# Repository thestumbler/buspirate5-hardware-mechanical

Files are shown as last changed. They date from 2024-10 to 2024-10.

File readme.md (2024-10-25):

# Bus Pirate 5, Mechanical Envelope Drawing

This repo has some scripts to enable semi-automatic preparation of
mechanical envelope drawing of the Bus Pirate 5 enclosure. 

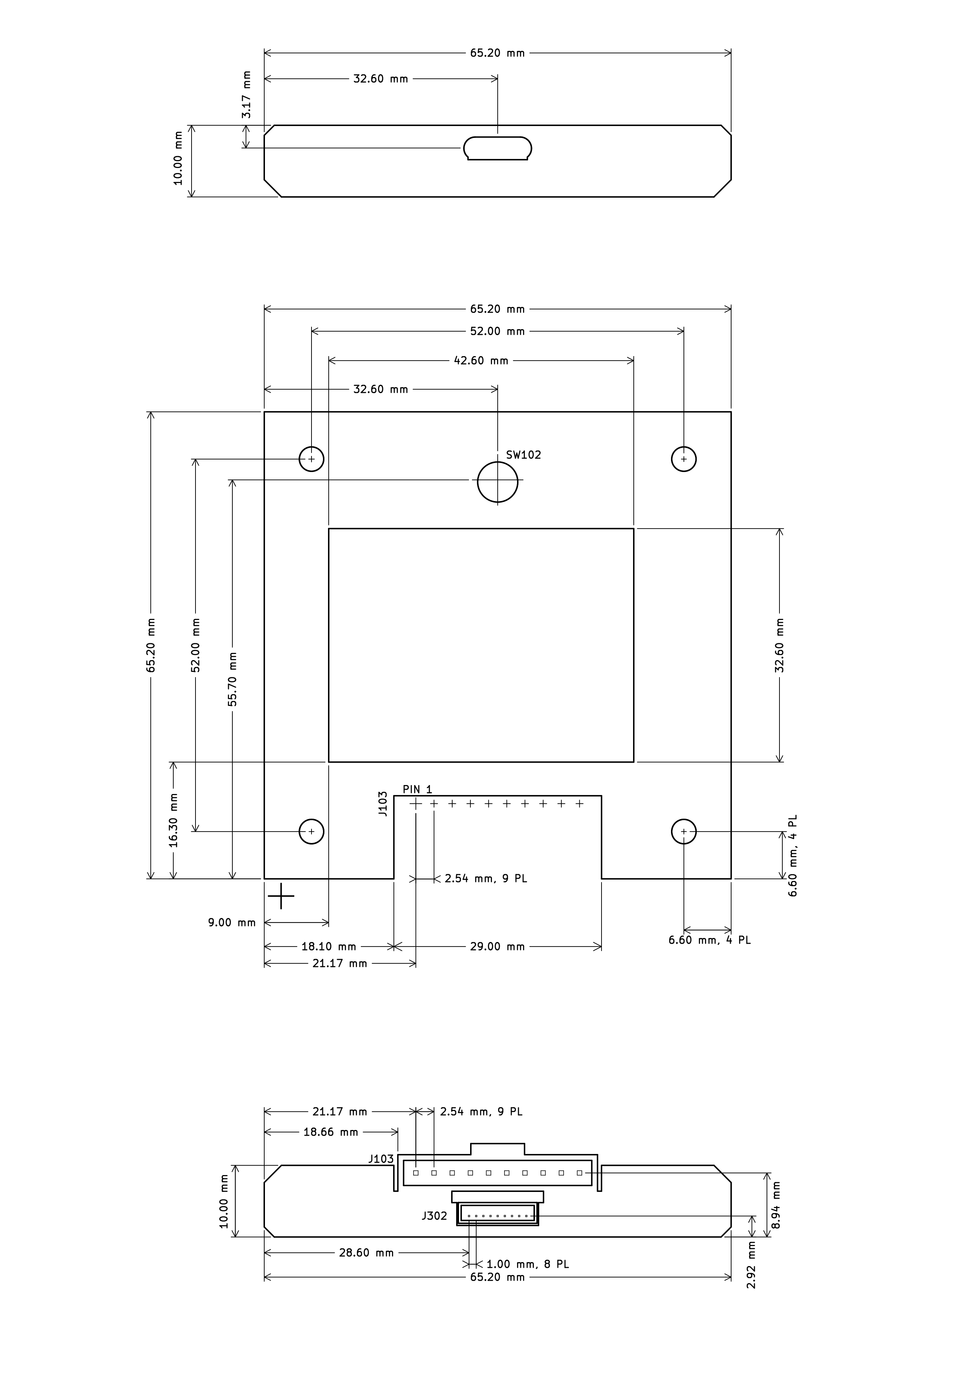
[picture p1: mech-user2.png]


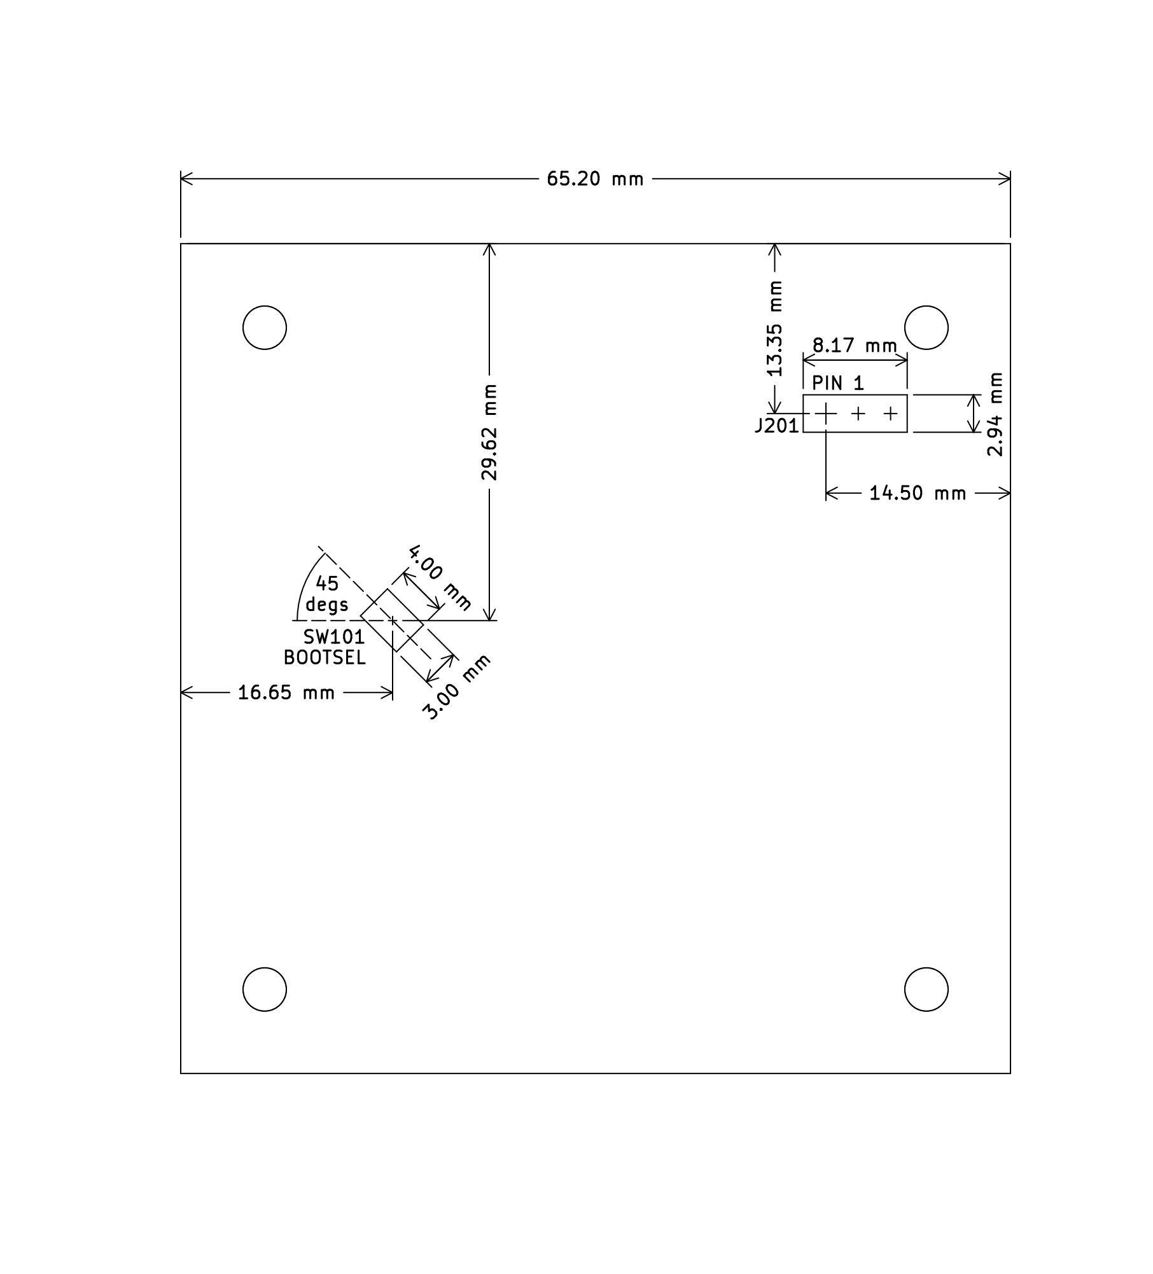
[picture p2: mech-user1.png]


## Background

The enclosure is designed in OpenSCAD. Getting 2D dimension drawings out
of OpenSCAD, while possible, is awkward ( see this [repo](
https://github.com/pwpearson/dimensional-drawings.git) for example ).
It is straightforward to make an XY projection or cut of an object. 
And KiCad has basic dimensioning for several versions now. So the
approach taken is

(1) create projections using OpenSCAD design
(2) save as DXF files, import into KiCad
(3) add dimensioning in KiCad

## OpenSCAD Projections

The file `make2d.scad` contains the for projecting the
different views. The code is organized as follows:

* module fiducial()
* module scad2kicad()
* module scad2kicad_sides()
* module project()
* module project_aux_side()
* module project_usb_side()
* // Main Slicing Code...

In summary, this requires the following 
operations (details are in the code):

* X-Y translation
* Mirroring
* Rotation
* Matching origin

This code could be put directly in the SCAD file. But there are several
versions to deal with, and it would be nice to keep this code separate.
The code is substantially independent, although it reaches into the
enclosure file to get the objects needed.

The only problem encountered with this approach is with OpenSCAD
importing of modules.

* If you `include` a file, you pickup all the modules and variables, but
  you also get any objects that are drawn in the main code.

* If you `use` a file, you get all the modules, any objects are not
  drawn, but you don't get the variables.

I don't have a solution for this. What I did was a compromise. I moved
all the parameters in the enclosure design to a file `params.scad`. 
If this is adopted, then all the versions of the enclosure would need to
carve out the variables into separate parameter files.

One other option is to organize the enclosure files so they don't create
any mainline objects without a control flag. This makes is easy to
include the files as-is, and use flags in the user customizer panel. See
`make2d.scad` for an example of this.

## KiCad Import

Importing the DXF files into KiCad is made easy by positioning the XY
projections in OpenSCAD so they match the exact placement of the PCB in
KiCAD. You can just import the files referenced to (0,0) and there is no
need to use interactive placement.

Four new layers are created as follows:

* User1  Bottom XY projection
* User2  Top and Sides projections
* User3  Bottom dimensions
* User4  Top and Sides dimensions

Dimensions are made by hand. 

## Revisions

All these four layers are kept in a separete PCB design `mech`. This
deisng only has four layers, the four user layers. If you make a new
BusPirate revision, you to the `append board` operation to add these to
the design.

If there are changes to the enclosure design, you have to remake the DXF
files and reimport them into KiCad. For most changes, it is easy to 
tweak the dimension layers to match any changes. The shell script
`make2d.sh` creates all four DXF files at once. 

As currently coded, you meed to manually edit the include statement in
make2d.scad (the target file of an include/use cannot be a variable).

# Resources

- [Download the latest firmware build](https://forum.buspirate.com/t/bus-pirate-5-auto-build-main-branch/20/99999)
- [Get help and chat in the forum](https://forum.buspirate.com/)
- [Firmware documentation](https://firmware.buspirate.com/) ([source](https://github.com/DangerousPrototypes/BusPirate5-docs-firmware))
- [Hardware documentation](https://hardware.buspirate.com/) ([source](https://github.com/DangerousPrototypes/BusPirate5-docs-hardware))
- [Hardware repo](https://github.com/DangerousPrototypes/BusPirate5-hardware)
- [Firmware repo](https://github.com/DangerousPrototypes/BusPirate5-firmware)

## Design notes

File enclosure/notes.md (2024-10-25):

button hole

line widths plotting

side projections nightmare

import board

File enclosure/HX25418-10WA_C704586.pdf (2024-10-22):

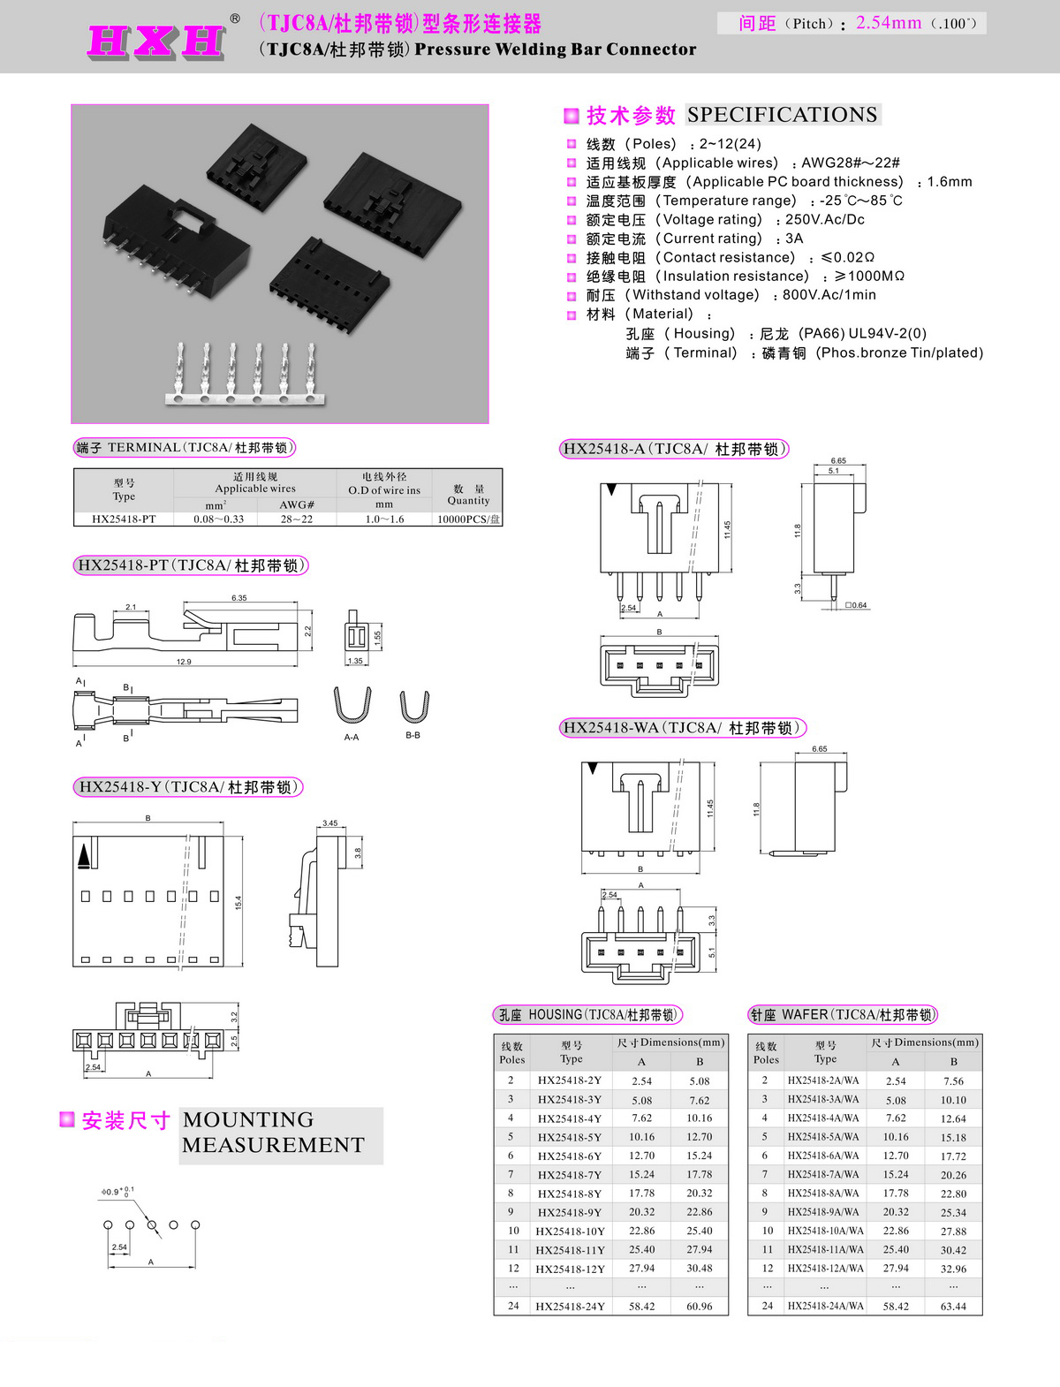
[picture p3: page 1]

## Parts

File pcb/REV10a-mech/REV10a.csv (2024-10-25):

Source: | C:\buspirate5-hardware\pcb\REV10a\REV10a.kicad_sch
Date: | 2/22/2024 12:56:02 PM
Tool: | Eeschema 7.0.7
Generator: | C:\Program Files\KiCad\7.0\bin\scripting\plugins/bom_csv_grouped_by_value.py
Component Count: | 220
Collated Components:
Item | Qty | Reference(s) | Value | LibPart | Footprint | Datasheet | DNP | Field4 | Field5 | Field6 | RMB | Sim.Device | Sim.Pins | Supplier | USD
1 | 58 | C103, C110, C111, C112, C113, C114, C115, C116, C117, C118, C121, C301, C302, C303, C304, C305, C306, C307, C308, C309, C310, C311, C312, C313, C314, C315, C316, C403, C406, C414, C415, C416, C501, C502, C503, C506, C508, C510, C602, C605, C701, C702, C703, C704, C705, C706, C707, C708, C710, C712, C713, C714, C715, C716, C717, C718, C719, C720 | 0.1uF | Device:C_Small | Capacitor_SMD:C_0402_1005Metric | ~ |  |  |  |  | 0.00628 |  |  | https://item.szlcsc.com/1877.html
2 | 10 | C104, C107, C108, C109, C405, C413, C504, C507, C509, C601 | 2.2uF | Device:C_Small | Capacitor_SMD:C_0402_1005Metric | ~ |  |  |  |  | 0.043101 |  |  | https://item.szlcsc.com/108589.html
3 | 2 | C105, C106 | 15pF | Device:C_Small | Capacitor_SMD:C_0402_1005Metric | ~ |  |  |  |  | 0.022142 |  |  | https://item.szlcsc.com/306263.html
4 | 6 | C201, C202, C401, C402, C404, C407 | 4.7uF | Device:C_Small | Capacitor_SMD:C_0402_1005Metric | ~ |  |  |  |  | 0.037726 |  |  | https://item.szlcsc.com/1877.html
5 | 1 | C408 | 120pF | Device:C_Small | Capacitor_SMD:C_0402_1005Metric | ~ |  |  |  |  | 0.037726 |  |  | https://item.szlcsc.com/1877.html
6 | 1 | C603 | DNF | Device:C_Small | Capacitor_SMD:C_0402_1005Metric | ~
7 | 4 | D401, D601, D602, D603 | 1N4148WT | Diode:1N4148WS | Diode_SMD:D_SOD-523 | https://www.vishay.com/docs/85751/1n4148ws.pdf |  |  |  |  | 0.182079 | D | 1=K 2=A | https://item.szlcsc.com/120141.html
8 | 5 | D500, D501, D502, D503, D504 | BAS40T-05 | Diode:BAT54C | Package_TO_SOT_SMD:SOT-523 | http://www.diodes.com/_files/datasheets/ds11005.pdf
9 | 5 | FID1, FID2, FID3, FID4, FID5 | Fiducial | Mechanical:Fiducial | Fiducial:Fiducial_1mm_Mask2mm | ~
10 | 4 | H1, H2, H3, H4 | MountingHole | Mechanical:MountingHole | MountingHole:MountingHole_3.2mm_M3 | ~
11 | 1 | J201 | Conn_01x03 | Connector_Generic:Conn_01x03 | Connector_PinSocket_2.54mm:PinSocket_1x03_P2.54mm_Vertical | ~
12 | 1 | J202 | TYPE-C-31-M-12 | :TYPE-C-31-M-12_2 | usb-c:HRO_TYPE-C-31-M-12 | HRO Electronics |  | 3.31mm | A | Manufacturer Recommendations
13 | 1 | J301 | Conn_01x10 | Connector_Generic:Conn_01x10 | Connector_PinHeader_2.54mm:PinHeader_1x10_P2.54mm_Vertical | ~
14 | 1 | J302 | Conn_01x09 | Connector_Generic:Conn_01x09 | Connector_JST:JST_SH_SM09B-SRSS-TB_1x09-1MP_P1.00mm_Horizontal | ~
15 | 1 | L201 | 1.5A | kicad5-device:Ferrite_Bead_Small | Inductor_SMD:L_0805_2012Metric | ~ |  |  |  |  | 0.175802 0.175802 |  |  | https://item.szlcsc.com/263551.html
16 | 1 | LCD201 | TFT_20_QT200H1201 | dp-lcd:TFT_20_QT200H1201 | dp-lcd:TFT_20_QT200H1201
17 | 8 | LED701, LED704, LED707, LED708, LED712, LED716, LED717, LED720 | SK6812-side-a_b | dp-LED:SK6812-side-a_b | dp-LED:SK6812-side-a_b
18 | 10 | LED702, LED703, LED705, LED706, LED710, LED713, LED714, LED715, LED718, LED719 | SK6812-mini-e | dp-LED:SK6812-mini-e | dp-LED:SK6812-mini-e |  |  |  |  |  | 0.5296 |  |  | https://item.szlcsc.com/542109.html
19 | 1 | logo1 | fcc_logo | DP_logo_kicad:fcc_logo | dp-logo:logo_fcc
20 | 1 | Q202 | MMBT7002K | Transistor_FET:BSS138 | Package_TO_SOT_SMD:SOT-23 | https://www.fairchildsemi.com/datasheets/BS/BSS138.pdf |  |  |  |  | 0.140017 |  |  | https://item.szlcsc.com/544697.html
21 | 10 | Q300, Q301, Q302, Q303, Q304, Q305, Q306, Q307, Q402, Q602 | SI2301 | Transistor_FET:BSS84 | Package_TO_SOT_SMD:SOT-523 | http://assets.nexperia.com/documents/data-sheet/BSS84.pdf |  |  |  |  | 0.232494 |  |  | https://item.szlcsc.com/76686.html
22 | 1 | Q401 | BCM857 | kicad5-device:Q_DUAL_PNP_PNP_E1B1C2E2B2C1 | Package_TO_SOT_SMD:SOT-363_SC-70-6 | ~
23 | 1 | Q601 | MMDT3906 | kicad5-device:Q_DUAL_PNP_PNP_E1B1C2E2B2C1 | Package_TO_SOT_SMD:SOT-363_SC-70-6 | ~
24 | 4 | R101, R502, R602, R603 | 1K | Device:R_Small | Resistor_SMD:R_0402_1005Metric | ~ |  |  |  |  | 0.006373 |  |  | https://item.szlcsc.com/116008.html
25 | 1 | R102 | DNF | Device:R_Small | Resistor_SMD:R_0402_1005Metric | ~ |  |  |  |  | 0.006373 |  |  | https://item.szlcsc.com/116008.html
26 | 4 | R103, R208, R608, R612 | 200R | Device:R_Small | Resistor_SMD:R_0402_1005Metric | ~ |  |  |  |  | 0.006373 |  |  | https://item.szlcsc.com/116008.html
27 | 2 | R201, R204 | 5.1K | Device:R_Small | Resistor_SMD:R_0402_1005Metric | ~ |  |  |  |  | 0.0065 |  |  | https://item.szlcsc.com/107087.html
28 | 2 | R202, R203 | 22R | Device:R_Small | Resistor_SMD:R_0402_1005Metric | ~ |  |  |  |  | 0.006505 |  |  | https://item.szlcsc.com/116009.html
29 | 1 | R209 | 33R | Device:R_Small | Resistor_SMD:R_0805_2012Metric | ~ |  |  |  |  | 0.019315 |  |  | https://item.szlcsc.com/139271.html
30 | 14 | R301, R313, R402, R406, R407, R410, R414, R415, R501, R606, R609, R610, R611, R613 | 10K | Device:R_Small | Resistor_SMD:R_0402_1005Metric | ~ |  |  |  |  | 0.005749 |  |  | https://item.szlcsc.com/61543.html
31 | 2 | R316, R320 | 510R | Device:R_Small | Resistor_SMD:R_0402_1005Metric | ~ |  |  |  |  | 0.004864 |  |  | https://item.szlcsc.com/61542.html
32 | 3 | R319, R401, R412 | 100K | Device:R_Small | Resistor_SMD:R_0402_1005Metric | ~ |  |  |  |  | 0.004864 |  |  | https://item.szlcsc.com/61542.html
33 | 1 | R403 | 102K | Device:R_Small | Resistor_SMD:R_0402_1005Metric | ~ |  |  |  |  | 0.005944 |  |  | https://item.szlcsc.com/174835.html
34 | 1 | R404 | 133K | Device:R_Small | Resistor_SMD:R_0402_1005Metric | ~ |  |  |  |  | 0.005749 |  |  | https://item.szlcsc.com/61543.html
35 | 5 | R405, R408, R409, R604, R605 | 33K | Device:R_Small | Resistor_SMD:R_0402_1005Metric | ~ |  |  |  |  | 0.004864 |  |  | https://item.szlcsc.com/61542.html
36 | 1 | R601 | 0R2 | Device:R | Resistor_SMD:R_2512_6332Metric_Pad1.40x3.35mm_HandSolder | ~ |  |  |  |  | 0.418328 |  |  | https://item.szlcsc.com/464030.html
37 | 4 | RN301, RN305, RN306, RN309 | 330R | dp-rarray:R_Array | Resistor_SMD:R_Array_Convex_4x0402 | http://www.vishay.com/docs/31509/csc.pdf |  |  |  |  | 0.033552 |  |  | https://item.szlcsc.com/26241.html
38 | 4 | RN302, RN304, RN307, RN310 | 1M | dp-rarray:R_Array | Resistor_SMD:R_Array_Convex_4x0402 | http://www.vishay.com/docs/31509/csc.pdf |  |  |  |  | 0.03666 |  |  | https://item.szlcsc.com/635571.html
39 | 4 | RN303, RN308, RN317, RN318 | 100K | dp-rarray:R_Array | Resistor_SMD:R_Array_Convex_4x0402 | http://www.vishay.com/docs/31509/csc.pdf |  |  |  |  | 0.020173 |  |  | https://item.szlcsc.com/728291.html
40 | 2 | RN311, RN312 | 10K | dp-rarray:R_Array | Resistor_SMD:R_Array_Convex_4x0402 | http://www.vishay.com/docs/31509/csc.pdf |  |  |  |  | 0.034572 |  |  | https://item.szlcsc.com/45893.html
41 | 4 | RN315, RN400, RN401, RN402 | 510R | dp-rarray:R_Array | Resistor_SMD:R_Array_Convex_4x0402 | http://www.vishay.com/docs/31509/csc.pdf |  |  |  |  | 0.033552 |  |  | https://item.szlcsc.com/26241.html
42 | 1 | SW101 | SW_SPST | Switch:SW_SPST | Button_Switch_SMD:SW_SPST_PTS810 | ~
43 | 1 | SW102 | 4P_button_sw | dp-switch:4P_button_sw | dp-switch:GT-TC026X-HXXX-LX
44 | 1 | U102 | W25Q128JVSIQ | dp-memory:xm25qh128a | Package_SO:SOP-8_5.28x5.23mm_P1.27mm |  |  |  |  |  | 9.85 |  |  | https://item.szlcsc.com/98729.html
45 | 1 | U103 | RP2040 | RP_Silicon:RP2040 | RP_Silicon:RP2040-QFN-56 |  |  |  |  |  |  |  |  |  | 1
46 | 1 | U105 | MT29F1G01ABAFDWB | dp-memory:MT29F1G01ABAFDWB | dp-memory:U-PDFN-8
47 | 8 | U301, U302, U303, U304, U305, U306, U307, U308 | AiP74LVC1T45GC363.TR | Logic_LevelTranslator:SN74LVC1T45DCK | Package_TO_SOT_SMD:SOT-363_SC-70-6 | http://www.ti.com/lit/ds/symlink/sn74lvc1t45.pdf |  |  |  |  | 1.33 |  |  | https://item.szlcsc.com/9911.html
48 | 1 | U401 | ME6211A33PG-N | Regulator_Linear:AP2204RA-3.3 | Package_TO_SOT_SMD:SOT-89-3 | https://www.diodes.com/assets/Datasheets/AP2204.pdf
49 | 1 | U402 | CD4067 | 74xx:CD74HC4067M | Package_SO:TSSOP-24_4.4x7.8mm_P0.65mm | http://www.ti.com/lit/ds/symlink/cd74hc4067.pdf |  |  |  |  |  |  |  | https://eu.mouser.com/ProductDetail/Nexperia/74HCT4067PW118 | 0.762
50 | 1 | U403 | AP2127 | dp-vreg:MCP1824 | Package_TO_SOT_SMD:SOT-23-5 |  |  |  |  |  | 2.68 |  |  | https://item.szlcsc.com/157049.html
51 | 3 | U404, U506, U603 | LMV321 | Comparator:LMV331 | Package_TO_SOT_SMD:SOT-23-5 | http://www.ti.com/lit/ds/symlink/lmv331.pdf
52 | 2 | U501, U502 | AIP74HC595TA | 74xx:74AHCT595 | Package_SO:TSSOP-16_4.4x5mm_P0.65mm | https://assets.nexperia.com/documents/data-sheet/74AHC_AHCT595.pdf |  |  |  |  | 0.8014 |  |  | https://item.szlcsc.com/163616.html
53 | 1 | U503 | AIP74HCT245TA | 74xx:74HC245 | Package_SO:TSSOP-20_4.4x6.5mm_P0.65mm | http://www.ti.com/lit/gpn/sn74HC245
54 | 2 | U504, U505 | LMV324 | Amplifier_Operational:LM324 | Package_SO:TSSOP-14_4.4x5mm_P0.65mm | http://www.ti.com/lit/ds/symlink/lm2902-n.pdf
55 | 1 | U601 | LMV321A | Comparator:LMV331 | Package_TO_SOT_SMD:SOT-23-5 | http://www.ti.com/lit/ds/symlink/lmv331.pdf
56 | 1 | U602 | LMV331 | Comparator:LMV331 | Package_TO_SOT_SMD:SOT-23-5 | http://www.ti.com/lit/ds/symlink/lmv331.pdf
57 | 1 | Y101 | 12Mhz | Device:Crystal_GND24_Small | Crystal:Crystal_SMD_3225-4Pin_3.2x2.5mm | ~ |  |  |  |  | 0.8432 |  |  | https://item.szlcsc.com/260706.html

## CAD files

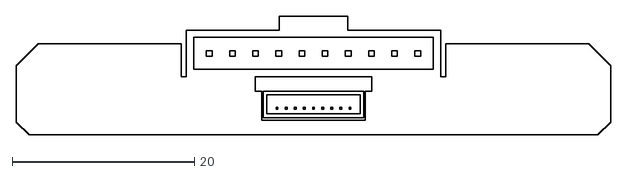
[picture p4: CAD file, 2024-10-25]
enclosure/enc-aux-side.dxf
65.2 x 13.0

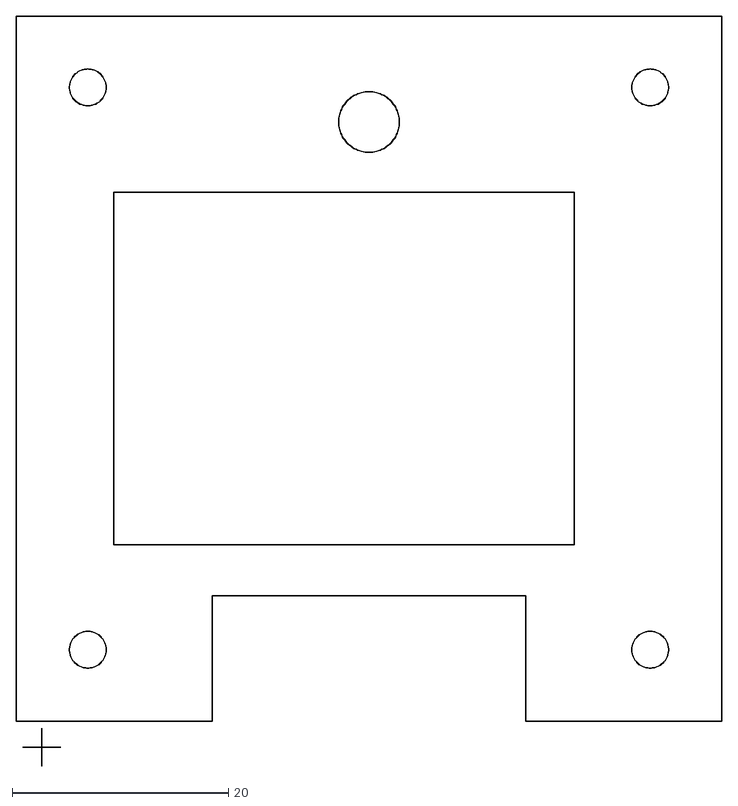
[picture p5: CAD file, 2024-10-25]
enclosure/enc-top.dxf
65.2 x 69.3

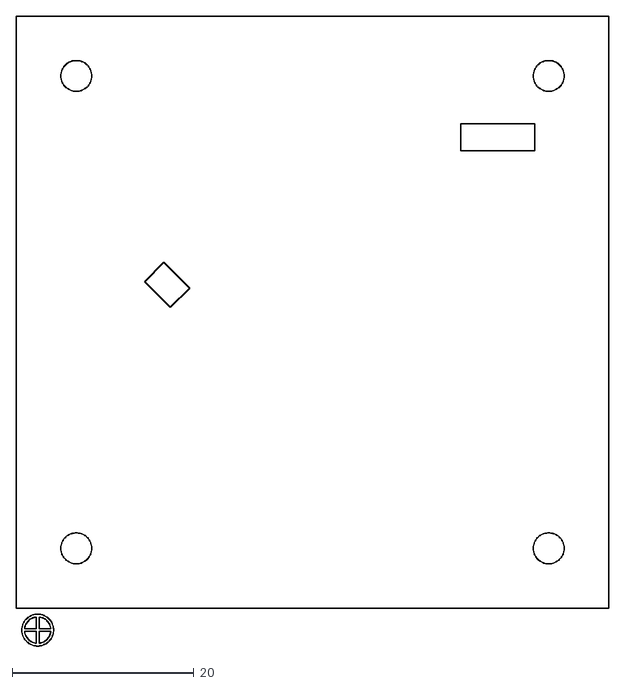
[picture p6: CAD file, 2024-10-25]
enclosure/enc-bottom.dxf
65.2 x 69.3

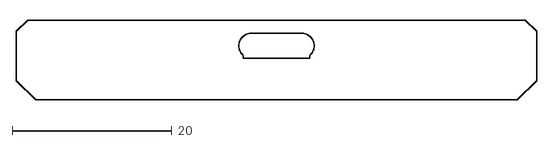
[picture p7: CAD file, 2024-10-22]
enclosure/enc-usb-side.dxf
65.2 x 10.0

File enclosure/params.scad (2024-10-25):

//epsilon value
eps=0.01;

//CASE BODY
//case stackup
echo("----------CASE----------");
face_h = 1.4;
lcd_h = 2.2;
pcb_h = 1.6;
standoff_h = 3.4;
floor_h = 1.4; //was 1.6... //was 2.4

top_h = face_h+lcd_h+pcb_h;
bottom_h = pcb_h+standoff_h+floor_h;
case_h=face_h+lcd_h+pcb_h+standoff_h+floor_h;
echo(top_h=top_h, bottom_h=bottom_h, case_h=case_h);

standoff_cut = 8.4; //length of the standoff arm excluding the rounded bit
standoff_d = 3; //diameter of standoff rounded bit

//mating walls
wall_inner_xy = 0.8; //inner wall thickness EACH side
wall_gap_xy=0.6; //was 0.6, but changed to one extruder width //gap between walls EACH side
wall_outer_xy=0.8; //outer wall thickness
wall_width=wall_inner_xy+wall_gap_xy+wall_outer_xy;
echo(wall_width=wall_width);

//pcb dimentions and tolerance
pcb_xy = 60;
pcb_tolerance_xy = 0.4; //spacing on EACH side
pcb_cavity_xy=(pcb_tolerance_xy*2)+pcb_xy; //bottom half PCB cavity
top_cavity_xy=pcb_cavity_xy+(wall_gap_xy*2)+(wall_inner_xy*2); //pcb+innerwall cavity in top
echo(pcb_cavity_xy=pcb_cavity_xy, top_cavity_xy=top_cavity_xy);

//full outer case dimentions
body_xy=(wall_outer_xy*2)+(wall_gap_xy*2)+(wall_inner_xy*2)+pcb_cavity_xy;
echo(body_xy=body_xy);

//edge chamfers, top and bottom
chamfer_top_h=2.4;
chamfer_bottom_h=1.4;

//TOP CASE FEATURES
//LCD body
lcd_x=34.6 + 2; //36.8;
lcd_y=47.8 + 2; //52.2;
//LCD viewable area
lcd_va_x=33.6 - 1; //32.4; 
lcd_va_y=43.6 - 1; //42.8;
lcd_va_base_h = 0.4; //two layers of material without chamfer on top of lcd
lcd_va_chamfer_h = face_h - lcd_va_base_h; //the chamfered "view port"
lcd_va_offset_y = 1.8 + (1/2); //from top of LCD body to top of viewable area

//10P header
head_10p_x = 11.6;
head_10p_y = 29.00;
head_10p_offset=4;

echo("------PROGRAMMING HEADER-------");
//cut in bottom of top half to accomidate the ends/solder of the programming header on the bottom layer
head_prog_x = 2.54+.4;
head_prog_y=(2.54*3)+0.55;
head_prog_bottom_h=lcd_h;  //bottom of header (top of PCB, top of case)
head_prog_top_h=floor_h;
head_prog_offset_x=10.75;
head_prog_offset_y=9.6;//9.6
head_prog_connector_max_h=floor_h+standoff_h;
echo(head_prog_connector_max_h=head_prog_connector_max_h);

//from datasheet for milled, low profile pin header
head_prog_connector_total_h=7.43;
head_prog_connector_pin_h=2.7;
head_prog_connector_body_h= head_prog_connector_total_h-head_prog_connector_pin_h;
head_prog_connector_clearance_h=head_prog_connector_max_h-head_prog_connector_body_h;
echo(head_prog_connector_body_h=head_prog_connector_body_h, head_prog_connector_clearance_h=head_prog_connector_clearance_h );

//mounting screws
echo("----------SCREWS----------");
screw_d=3.4;
screw_offset_xy=4;
screw_head_h=1.7;
screw_head_d1=screw_d;
screw_head_d2=6.2;
heatset_nut_d=4.4; //4.3/3.9;
heatset_nut_max_h=floor_h+standoff_h;
screw_distance_to_nut_h=top_h;
echo(screw_distance_to_nut_h=screw_distance_to_nut_h);

screw_h=8;
screw_depth_nut_h=screw_h-screw_distance_to_nut_h;
echo(screw_h=screw_h, screw_depth_nut_h=screw_depth_nut_h);

echo("----------NUTS----------");
heatset_nut_h=3;
heatset_nut_bottom_clearance_h=.8; //how much deeper should the hole be than the nut? effects minimum floor thickness
heatset_nut_unused_h=heatset_nut_h-screw_depth_nut_h;
echo(heatset_nut_max_h=heatset_nut_max_h);
echo(heatset_nut_h=heatset_nut_h,heatset_nut_unused_h=heatset_nut_unused_h);

//push buttons (with countersink)  
//assumes center button is at Y=0 (centered)  
echo("--------USER BUTTONS--------");
button_distance_to_top=face_h+lcd_h;
echo(button_distance_to_top=button_distance_to_top);

//button body cutout
butt_body_x=9.2;
butt_body_y=28; 
butt_body_h=1.5;
butt_body_cavity_h=0.8; 
echo(butt_body_cavity_h=butt_body_cavity_h);

//This is stack up for short buttons with button caps
butt_cap_h=4;
butt_cap_d=5+.4;
butt_cap_rim_h=1; 
butt_cap_rim_d=6.8+.4;
butt_cap_center_extra_space_d=0.2; //for some reason our printer makes the center hole slightly too tight, so we add some space
//This is the 1mm cap rim + 0.7 of the button body height +0.1 (even layer height)
//(to keep cap rim being stuck under the case)
butt_cap_rim_cavity_h=butt_cap_rim_h+(butt_body_h-butt_body_cavity_h)+.1;
echo(butt_cap_rim_cavity_h=butt_cap_rim_cavity_h);
butt_cap_shaft_h=button_distance_to_top-butt_body_cavity_h-butt_cap_rim_cavity_h;
echo(butt_cap_shaft_h=butt_cap_shaft_h);

//This is stack up with long shaft button
//counter sink 
butt_sink_h=1.7; 
butt_sink_d1=3.2;
butt_sink_d2=6.2;
//button hole
butt_offset_x=7.2; //edge of pcb to center of button
butt_spread_y=10; //center of center button to center of top and bottom buttons
butt_hole_d=3.2;
butt_hole_h=top_h-(pcb_h+butt_body_h+butt_sink_h);





//BOTTOM CASE FEATURES
//retaining lip for the case
bottom_lip_width=wall_gap_xy+wall_outer_xy;
bottom_lip_h=pcb_h;

//sd card hole
sd_x=14;
sd_y=wall_width;
sd_offset_x=22;
sd_h=3.4;

//9p aux la header hole
head_aux_x=wall_width;
head_aux_y=12.8;
head_aux_h=4.8;

//USB C hole (currently blown out)
usb_x=wall_width;
usb_y=14; //blow out
usb_h=5.6; //blow out, 3.2;
print_layer_h=0.2;
usb_cut_layers=2;

//bootloader button hole
bootload_x=3;
bootload_y=4;
bootload_h=floor_h;
bootload_offset_x=27; //from top of flipped PCB
bootload_offset_y=14;    //from right of flipped PCB
bootload_spin=45;
echo("----------END----------");

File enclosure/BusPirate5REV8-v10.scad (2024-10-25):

include <BOSL2/std.scad>
include <BOSL2/rounding.scad>
vf=360;
//version number
version="10"; //version number
version_h=1; //depth of version number pocket

//epsilon value
eps=0.01;

//CASE BODY
//case stackup
echo("----------CASE----------");
face_h = 1.4;
lcd_h = 2.2;
pcb_h = 1.6;
standoff_h = 3.4;
floor_h = 1.4; //was 1.6... //was 2.4

top_h = face_h+lcd_h+pcb_h;
bottom_h = pcb_h+standoff_h+floor_h;
case_h=face_h+lcd_h+pcb_h+standoff_h+floor_h;
echo(top_h=top_h, bottom_h=bottom_h, case_h=case_h);

standoff_cut = 8.4; //length of the standoff arm excluding the rounded bit
standoff_d = 3; //diameter of standoff rounded bit

//mating walls
wall_inner_xy = 0.8; //inner wall thickness EACH side
wall_gap_xy=0.6; //was 0.6, but changed to one extruder width //gap between walls EACH side
wall_outer_xy=0.8; //outer wall thickness
wall_width=wall_inner_xy+wall_gap_xy+wall_outer_xy;
echo(wall_width=wall_width);

//pcb dimentions and tolerance
pcb_xy = 60;
pcb_tolerance_xy = 0.4; //spacing on EACH side
pcb_cavity_xy=(pcb_tolerance_xy*2)+pcb_xy; //bottom half PCB cavity
top_cavity_xy=pcb_cavity_xy+(wall_gap_xy*2)+(wall_inner_xy*2); //pcb+innerwall cavity in top
echo(pcb_cavity_xy=pcb_cavity_xy, top_cavity_xy=top_cavity_xy);

//full outer case dimentions
body_xy=(wall_outer_xy*2)+(wall_gap_xy*2)+(wall_inner_xy*2)+pcb_cavity_xy;
echo(body_xy=body_xy);

//edge chamfers, top and bottom
chamfer_top_h=2.4;
chamfer_bottom_h=1.4;

//TOP CASE FEATURES
//LCD body
lcd_x=34.6 + 2; //36.8;
lcd_y=47.8 + 2; //52.2;
//LCD viewable area
lcd_va_x=33.6 - 1; //32.4; 
lcd_va_y=43.6 - 1; //42.8;
lcd_va_base_h = 0.4; //two layers of material without chamfer on top of lcd
lcd_va_chamfer_h = face_h - lcd_va_base_h; //the chamfered "view port"
lcd_va_offset_y = 1.8 + (1/2); //from top of LCD body to top of viewable area

//10P header
head_10p_x = 11.6;
head_10p_y = 29.00;
head_10p_offset=4;

echo("------PROGRAMMING HEADER-------");
//cut in bottom of top half to accomidate the ends/solder of the programming header on the bottom layer
head_prog_x = 2.54+.4;
head_prog_y=(2.54*3)+0.55;
head_prog_bottom_h=lcd_h;  //bottom of header (top of PCB, top of case)
head_prog_top_h=floor_h;
head_prog_offset_x=10.75;
head_prog_offset_y=9.6;//9.6
head_prog_connector_max_h=floor_h+standoff_h;
echo(head_prog_connector_max_h=head_prog_connector_max_h);

//from datasheet for milled, low profile pin header
head_prog_connector_total_h=7.43;
head_prog_connector_pin_h=2.7;
head_prog_connector_body_h= head_prog_connector_total_h-head_prog_connector_pin_h;
head_prog_connector_clearance_h=head_prog_connector_max_h-head_prog_connector_body_h;
echo(head_prog_connector_body_h=head_prog_connector_body_h, head_prog_connector_clearance_h=head_prog_connector_clearance_h );

//mounting screws
echo("----------SCREWS----------");
screw_d=3.4;
screw_offset_xy=4;
screw_head_h=1.7;
screw_head_d1=screw_d;
screw_head_d2=6.2;
heatset_nut_d=4.4; //4.3/3.9;
heatset_nut_max_h=floor_h+standoff_h;
screw_distance_to_nut_h=top_h;
echo(screw_distance_to_nut_h=screw_distance_to_nut_h);

screw_h=8;
screw_depth_nut_h=screw_h-screw_distance_to_nut_h;
echo(screw_h=screw_h, screw_depth_nut_h=screw_depth_nut_h);

echo("----------NUTS----------");
heatset_nut_h=3;
heatset_nut_bottom_clearance_h=.8; //how much deeper should the hole be than the nut? effects minimum floor thickness
heatset_nut_unused_h=heatset_nut_h-screw_depth_nut_h;
echo(heatset_nut_max_h=heatset_nut_max_h);
echo(heatset_nut_h=heatset_nut_h,heatset_nut_unused_h=heatset_nut_unused_h);

//push buttons (with countersink)  
//assumes center button is at Y=0 (centered)  
echo("--------USER BUTTONS--------");
button_distance_to_top=face_h+lcd_h;
echo(button_distance_to_top=button_distance_to_top);

//button body cutout
butt_body_x=9.2;
butt_body_y=28; 
butt_body_h=1.5;
butt_body_cavity_h=0.8; 
echo(butt_body_cavity_h=butt_body_cavity_h);

//This is stack up for short buttons with button caps
butt_cap_h=4;
butt_cap_d=5+.4;
butt_cap_rim_h=1; 
butt_cap_rim_d=6.8+.4;
butt_cap_center_extra_space_d=0.2; //for some reason our printer makes the center hole slightly too tight, so we add some space
//This is the 1mm cap rim + 0.7 of the button body height +0.1 (even layer height)
//(to keep cap rim being stuck under the case)
butt_cap_rim_cavity_h=butt_cap_rim_h+(butt_body_h-butt_body_cavity_h)+.1;
echo(butt_cap_rim_cavity_h=butt_cap_rim_cavity_h);
butt_cap_shaft_h=button_distance_to_top-butt_body_cavity_h-butt_cap_rim_cavity_h;
echo(butt_cap_shaft_h=butt_cap_shaft_h);

//This is stack up with long shaft button
//counter sink 
butt_sink_h=1.7; 
butt_sink_d1=3.2;
butt_sink_d2=6.2;
//button hole
butt_offset_x=7.2; //edge of pcb to center of button
butt_spread_y=10; //center of center button to center of top and bottom buttons
butt_hole_d=3.2;
butt_hole_h=top_h-(pcb_h+butt_body_h+butt_sink_h);





//BOTTOM CASE FEATURES
//retaining lip for the case
bottom_lip_width=wall_gap_xy+wall_outer_xy;
bottom_lip_h=pcb_h;

//sd card hole
sd_x=14;
sd_y=wall_width;
sd_offset_x=22;
sd_h=3.4;

//9p aux la header hole
head_aux_x=wall_width;
head_aux_y=12.8;
head_aux_h=4.8;

//USB C hole (currently blown out)
usb_x=wall_width;
usb_y=14; //blow out
usb_h=5.6; //blow out, 3.2;
print_layer_h=0.2;
usb_cut_layers=2;

//bootloader button hole
bootload_x=3;
bootload_y=4;
bootload_h=floor_h;
bootload_offset_x=27; //from top of flipped PCB
bootload_offset_y=14;    //from right of flipped PCB
bootload_spin=45;
echo("----------END----------");

//
// CASE TOP MODULES
//
module body_top(){
    //case body
    // diff("mask"){
    diff(){
        cube(size=[body_xy, body_xy,top_h], anchor=BOTTOM){
            //top chamfer
            chamfer_list=[RIGHT, LEFT, BACK, FRONT];
            for( i = chamfer_list){
            edge_mask(TOP+i)
                chamfer_edge_mask(l=body_xy, chamfer=chamfer_top_h);
            }                        
        }    
    }
}

module cavity_top(){    
    //PCB area in top
    translate([0,0,-eps]){
        cube(size=[top_cavity_xy, top_cavity_xy, pcb_h+eps], anchor=BOTTOM);
    }
}

module lcd(){
    //LCD
    lcd_va_chamfer_eps_h=lcd_va_chamfer_h+eps+eps;
    translate([0,0,pcb_h]){
        union(){
            //body
            translate([0,0,-eps]){
                cube(size=[lcd_x, lcd_y, lcd_h+eps], anchor=BOTTOM);
            }
            //view area base (0.4=2 layers)
             translate([0, lcd_va_offset_y, lcd_h-eps]){
                 cube(size=[lcd_va_x, lcd_va_y, lcd_va_base_h+eps], anchor=BOTTOM);
            }           
            //view area chamfer, 45 degrees
            translate([0, lcd_va_offset_y, (lcd_h+lcd_va_base_h)-eps]){
                prismoid(size1=[lcd_va_x, lcd_va_y], size2=[lcd_va_x+(lcd_va_chamfer_eps_h*2), lcd_va_y+(lcd_va_chamfer_eps_h*2)], h=lcd_va_chamfer_eps_h);
            }
        }
    }
}

module screws(){
    //screw holes
    for(a=[1:-2:-1]){
        for(b=[1:-2:-1]){
             translate([a*((pcb_xy/2)-screw_offset_xy),b*((pcb_xy/2)-screw_offset_xy),0]){
                union(){
                    //shaft
                    translate([0,0,-eps]){
                        cylinder(h=(top_h-screw_head_h)+eps, d=screw_d, anchor=BOTTOM, $fn=100);
                    }
                    //countersink
                    translate([0,0,top_h-screw_head_h-eps]){
                        cylinder(h = screw_head_h+eps+eps, d1 = screw_head_d1, d2 = screw_head_d2, anchor=BOTTOM, $fn=100);
                    }
                }
            }
        }
    }
}

module buttons(){
     //buttons
    translate([-((pcb_xy/2)-butt_offset_x), 0,pcb_h]){
        union(){
            //button body
            translate([0,0,-eps]){
                cube(size=[butt_body_x, butt_body_y, butt_body_cavity_h+eps], anchor=BOTTOM);
            }
            //button holes
            if(0){
            //for(a=[-1:1:1]){
                translate([ 0, butt_spread_y*a, butt_body_cavity_h]){
                    union(){
                        translate([0,0,-eps]){
                            cylinder(h=butt_hole_h+eps , d=butt_hole_d, anchor=BOTTOM, $fn=100);  
                        }
                        translate([0,0,butt_hole_h-eps]){
                            cylinder(h = butt_sink_h+eps+eps, d1 = butt_sink_d1, d2 = butt_sink_d2, anchor=BOTTOM, $fn=100);
                        }                         
                    }
                }
            //}
            }
        }
    }
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

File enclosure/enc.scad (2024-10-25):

include <BOSL2/std.scad>
include <BOSL2/rounding.scad>
include <BOSL2/screws.scad>

include <params.scad>

vf=360;
//version number
version="10"; //version number
version_h=1; //depth of version number pocket


use <hx10p.scad>

//
// CASE TOP MODULES
//
module body_top(){
    //case body
    diff(){
        cube(size=[body_xy, body_xy,top_h], anchor=BOTTOM){
            //top chamfer
            chamfer_list=[RIGHT, LEFT, BACK, FRONT];
            for( i = chamfer_list){
            edge_mask(TOP+i)
                chamfer_edge_mask(l=body_xy, chamfer=chamfer_top_h);
            }                        
        }    
    }
}

module cavity_top(){    
    //PCB area in top
    translate([0,0,-eps]){
        cube(size=[top_cavity_xy, top_cavity_xy, pcb_h+eps], anchor=BOTTOM);
    }
}

module lcd(){
    //LCD
    lcd_va_chamfer_eps_h=lcd_va_chamfer_h+eps+eps;
    translate([0,0,pcb_h]){
        union(){
            //body
            translate([0,0,-eps]){
                cube(size=[lcd_x, lcd_y, lcd_h+eps], anchor=BOTTOM);
            }
            //view area base (0.4=2 layers)
             translate([0, lcd_va_offset_y, lcd_h-eps]){
                 cube(size=[lcd_va_x, lcd_va_y, lcd_va_base_h+eps], anchor=BOTTOM);
            }           
            //view area chamfer, 45 degrees
            translate([0, lcd_va_offset_y, (lcd_h+lcd_va_base_h)-eps]){
                prismoid(size1=[lcd_va_x, lcd_va_y], size2=[lcd_va_x+(lcd_va_chamfer_eps_h*2), lcd_va_y+(lcd_va_chamfer_eps_h*2)], h=lcd_va_chamfer_eps_h);
            }
        }
    }
}

module screws(){
    //screw holes
    for(a=[1:-2:-1]){
        for(b=[1:-2:-1]){
             translate([a*((pcb_xy/2)-screw_offset_xy),b*((pcb_xy/2)-screw_offset_xy),0]){
                union(){
                    //shaft
                    translate([0,0,-eps]){
                        cylinder(h=(top_h-screw_head_h)+eps, d=screw_d, anchor=BOTTOM, $fn=100);
                    }
                    //countersink
                    translate([0,0,top_h-screw_head_h-eps]){
                        cylinder(h = screw_head_h+eps+eps, d1 = screw_head_d1, d2 = screw_head_d2, anchor=BOTTOM, $fn=100);
                    }
                }
            }
        }
    }
}

module buttons(){
     //buttons
    translate([-((pcb_xy/2)-butt_offset_x), 0,pcb_h]){
        union(){
            //button body
            translate([0,0,-eps]){
                cube(size=[butt_body_x, butt_body_y, butt_body_cavity_h+eps], anchor=BOTTOM);
            }
            //button holes
            if(0){
            //for(a=[-1:1:1]){
                translate([ 0, butt_spread_y*a, butt_body_cavity_h]){
                    union(){
                        translate([0,0,-eps]){
                            cylinder(h=butt_hole_h+eps , d=butt_hole_d, anchor=BOTTOM, $fn=100);  
                        }
                        translate([0,0,butt_hole_h-eps]){
                            cylinder(h = butt_sink_h+eps+eps, d1 = butt_sink_d1, d2 = butt_sink_d2, anchor=BOTTOM, $fn=100);
                        }                         
                    }
                }
            //}
            }
        }
    }

    butt_cap_extra_clear_d=[0,butt_cap_center_extra_space_d,0];
    //button holes for caps
    //for(a=[-1:1:1]){
        a=0;
        translate([ -((pcb_xy/2)-butt_offset_x), butt_spread_y*a, pcb_h+butt_body_cavity_h-eps]){
            translate([0,0,-eps]){
                cylinder(h = butt_cap_rim_cavity_h + eps, d =(butt_cap_rim_d + butt_cap_extra_clear_d[a+1]), anchor=BOTTOM, $fn=100);
            }
            translate([0,0,butt_cap_rim_cavity_h-eps]){
                cylinder(h = butt_cap_h+eps, d = butt_cap_d + butt_cap_extra_clear_d[a+1], anchor=BOTTOM, $fn=100);
            }  
        }
    //}       
}

module header_10P(){
    //10p header
    translate([(body_xy/2)+eps,0,-eps]){
        cube(size=[head_10p_x+eps, head_10p_y, top_h+eps+eps], anchor=BOTTOM+RIGHT);
    }
}


module header_prog_top(){
    //programming header cutout
    translate([-1*((pcb_xy/2)-head_prog_offset_x),-1*((pcb_xy/2)-head_prog_offset_y),pcb_h-eps]){
        cube(size=[head_prog_x,head_prog_y,head_prog_bottom_h+eps], anchor=BOTTOM);
    }
}                                                       

//
// CASE BOTTOM MODULES
//
module body_bottom(){
    //bottom and chamfers
    diff(){
        cube(size=[body_xy, body_xy,bottom_h], anchor=BOTTOM){
            //bottom chamfer
            chamfer_list=[RIGHT, LEFT, BACK, FRONT];
            for( i = chamfer_list){
            edge_mask(BOTTOM+i)
                chamfer_edge_mask(l=body_xy, chamfer=chamfer_bottom_h);
            }                
        }   
    } 
} 

module pcb(){
    //PCB
    translate([0,0,(standoff_h+floor_h)]){
        cube(size=[pcb_cavity_xy, pcb_cavity_xy, pcb_h+eps], anchor=BOTTOM);
    }
}

module standoffs(){
    //standoffs
    standoff_edge = pcb_cavity_xy - (standoff_cut*2);
    shape = [[0,standoff_cut], [0,standoff_cut+standoff_edge], [standoff_cut,standoff_cut+standoff_edge], //left
            [standoff_cut,standoff_cut+standoff_edge+standoff_cut], [standoff_cut+standoff_edge, standoff_cut+standoff_edge+standoff_cut], [standoff_cut+standoff_edge, standoff_edge+standoff_cut], //top
            [standoff_cut+standoff_edge+standoff_cut, standoff_edge+standoff_cut], [standoff_cut+standoff_edge+standoff_cut,standoff_cut], [standoff_cut+standoff_edge,standoff_cut], //right
            [standoff_cut+standoff_edge,0], [standoff_cut,0], [standoff_cut,standoff_cut]]; //bottom
    radii = [0, 0, standoff_d, 0, 0, standoff_d, 0, 0, standoff_d, 0, 0, standoff_d];
    translate([-pcb_cavity_xy/2, -pcb_cavity_xy/2, floor_h]){
        linear_extrude(height=standoff_h+eps){
            polygon(round_corners(shape, radius = radii,$fn=64));
        }
    }  
}

module bottom_nuts(){
    //screw holes
    for(a=[1:-2:-1]){
        for(b=[1:-2:-1]){
           translate([a*((pcb_xy/2)-screw_offset_xy),b*((pcb_xy/2)-screw_offset_xy),heatset_nut_max_h-heatset_nut_h]){
                cylinder(h=heatset_nut_h+heatset_nut_bottom_clearance_h+eps, d=screw_d, anchor=BOTTOM, $fn=100);
           }

            translate([a*((pcb_xy/2)-screw_offset_xy),b*((pcb_xy/2)-screw_offset_xy),-eps]){
                cylinder(r=3.4, h=3.2+eps, $fn=6, anchor=BOTTOM);
            }
        }
    }    

   
}

module heatset_nuts_old(){
    //screw holes
    for(a=[1:-2:-1]){
        for(b=[1:-2:-1]){
            translate([a*((pcb_xy/2)-screw_offset_xy),b*((pcb_xy/2)-screw_offset_xy),heatset_nut_max_h-heatset_nut_h]){
                cylinder(h=heatset_nut_h+heatset_nut_bottom_clearance_h+eps, d=heatset_nut_d, anchor=BOTTOM, $fn=100);
                cylinder(r=3.4, h=5, $fn=6, anchor=BOTTOM);
            }
        }
    }    

   
}


module old_sd_card(){
    //sd card
    translate([-((body_xy/2)-sd_offset_x),-1*((body_xy/2)+eps),bottom_h+eps]){
        #cube(size=[sd_x,sd_y+eps+eps+eps,sd_h+eps], anchor=TOP+FRONT+LEFT);
    }    
}

module sd_card(){
    //la aux header
    //0.8mm straight (2 print beads)
    //rest chamfered (wall_width-0.8)

        //sd card
    translate([-((pcb_xy/2)-sd_offset_x),-1*((body_xy/2)-wall_width-eps),bottom_h+eps]){
        cube(size=[sd_x,0.8+eps+eps+eps,sd_h+eps], anchor=TOP+BACK+LEFT);
    }   

    translate([-((pcb_xy/2)-sd_offset_x), -1*((body_xy/2)-wall_width+0.8-eps), bottom_h-pcb_h]){
    rotate(a=[90,0,0]){        
        prismoid(size1=[sd_x,sd_h], size2=[sd_x+((wall_width-0.8)/2),sd_h+((wall_width-0.8)/2)], h=wall_width-0.8+eps+eps, anchor=BOTTOM+LEFT);
    }

    }
}

module header_aux(){
    //la aux header
    //0.8mm straight (2 print beads)
    //rest chamfered (wall_width-0.8)

   /* translate([(body_xy/2)-wall_width-eps, 0, bottom_h-pcb_h-head_aux_x]){
        cube(size=[0.8+eps+eps+eps,head_aux_y,case_h], anchor=BOTTOM+LEFT);
     }

    translate([(body_xy/2)-eps-(wall_width-.8), 0, bottom_h-pcb_h]){
    rotate(a=[0,90,0]){        
        prismoid(size1=[head_aux_x,head_aux_y], size2=[head_aux_x+((wall_width-0.8)/2),head_aux_y+((wall_width-0.8)/2)], h=wall_width-0.8+eps+eps, anchor=BOTTOM+LEFT);
    }

    }*/

    translate([(body_xy/2)+eps, 0, bottom_h+eps]){
        cube(size=[head_aux_x+eps+eps,head_aux_y,head_aux_h], anchor=TOP+RIGHT);
    }   


}

module usb_bottom(){
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

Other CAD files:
enclosure/hx10p.scad
enclosure/make2d.scad
enclosure/ref.scad
enclosure/test.scad
enclosure/wr9p.scad

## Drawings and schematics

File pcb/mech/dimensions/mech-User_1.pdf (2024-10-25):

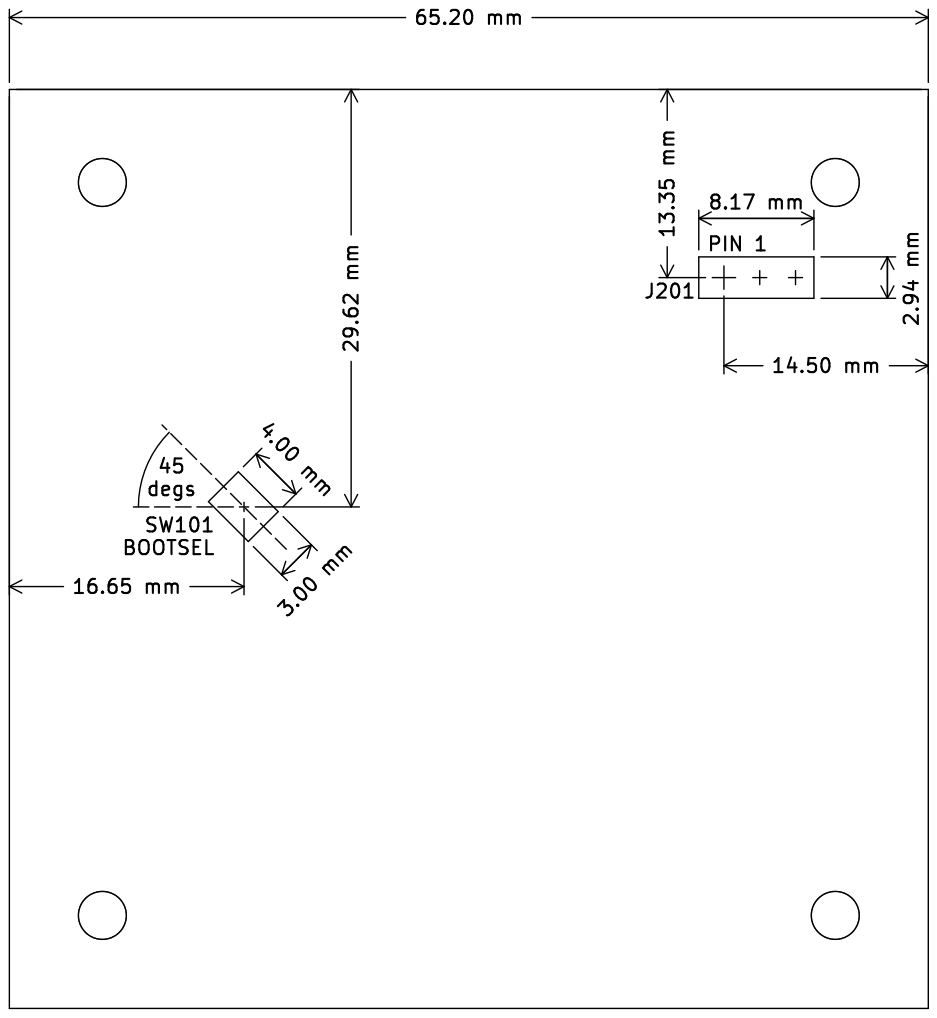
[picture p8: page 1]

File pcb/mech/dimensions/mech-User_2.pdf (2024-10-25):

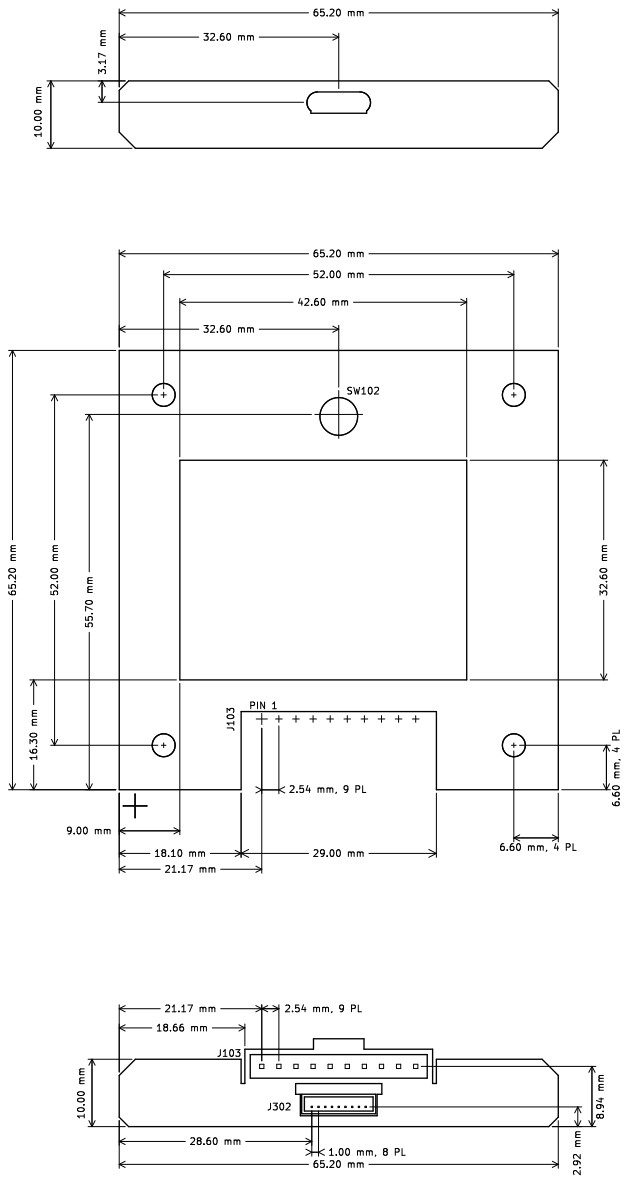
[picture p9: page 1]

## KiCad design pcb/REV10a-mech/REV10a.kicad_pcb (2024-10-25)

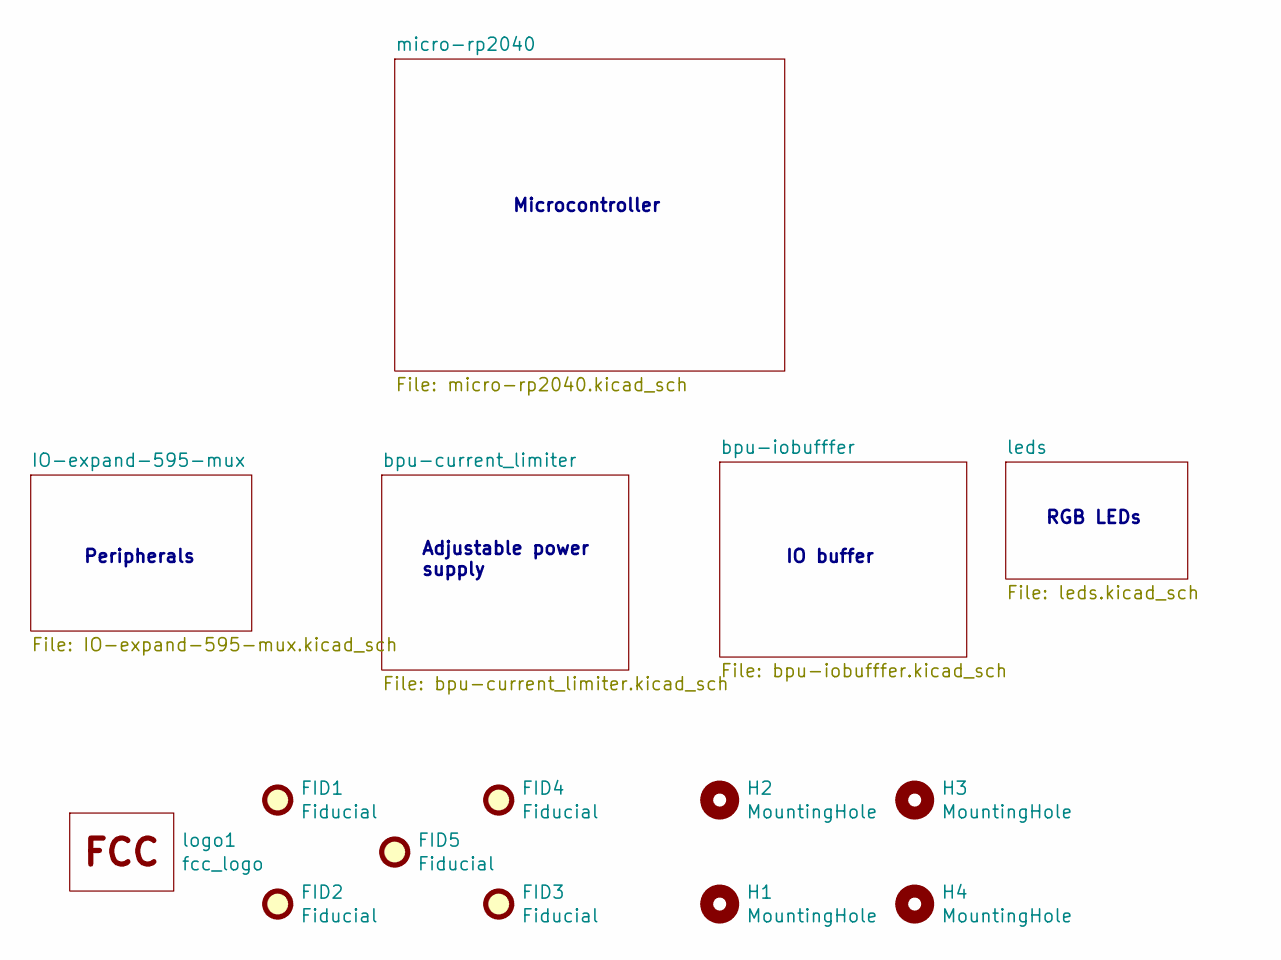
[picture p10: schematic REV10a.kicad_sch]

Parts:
FID1, FID2, FID3, FID4, FID5: Fiducial; Fiducial_1mm_Mask2mm
H1, H2, H3, H4: MountingHole; MountingHole_3.2mm_M3
logo1: fcc_logo; logo_fcc

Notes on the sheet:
Microcontroller
Adjustable power supply
IO buffer
Peripherals
RGB LEDs

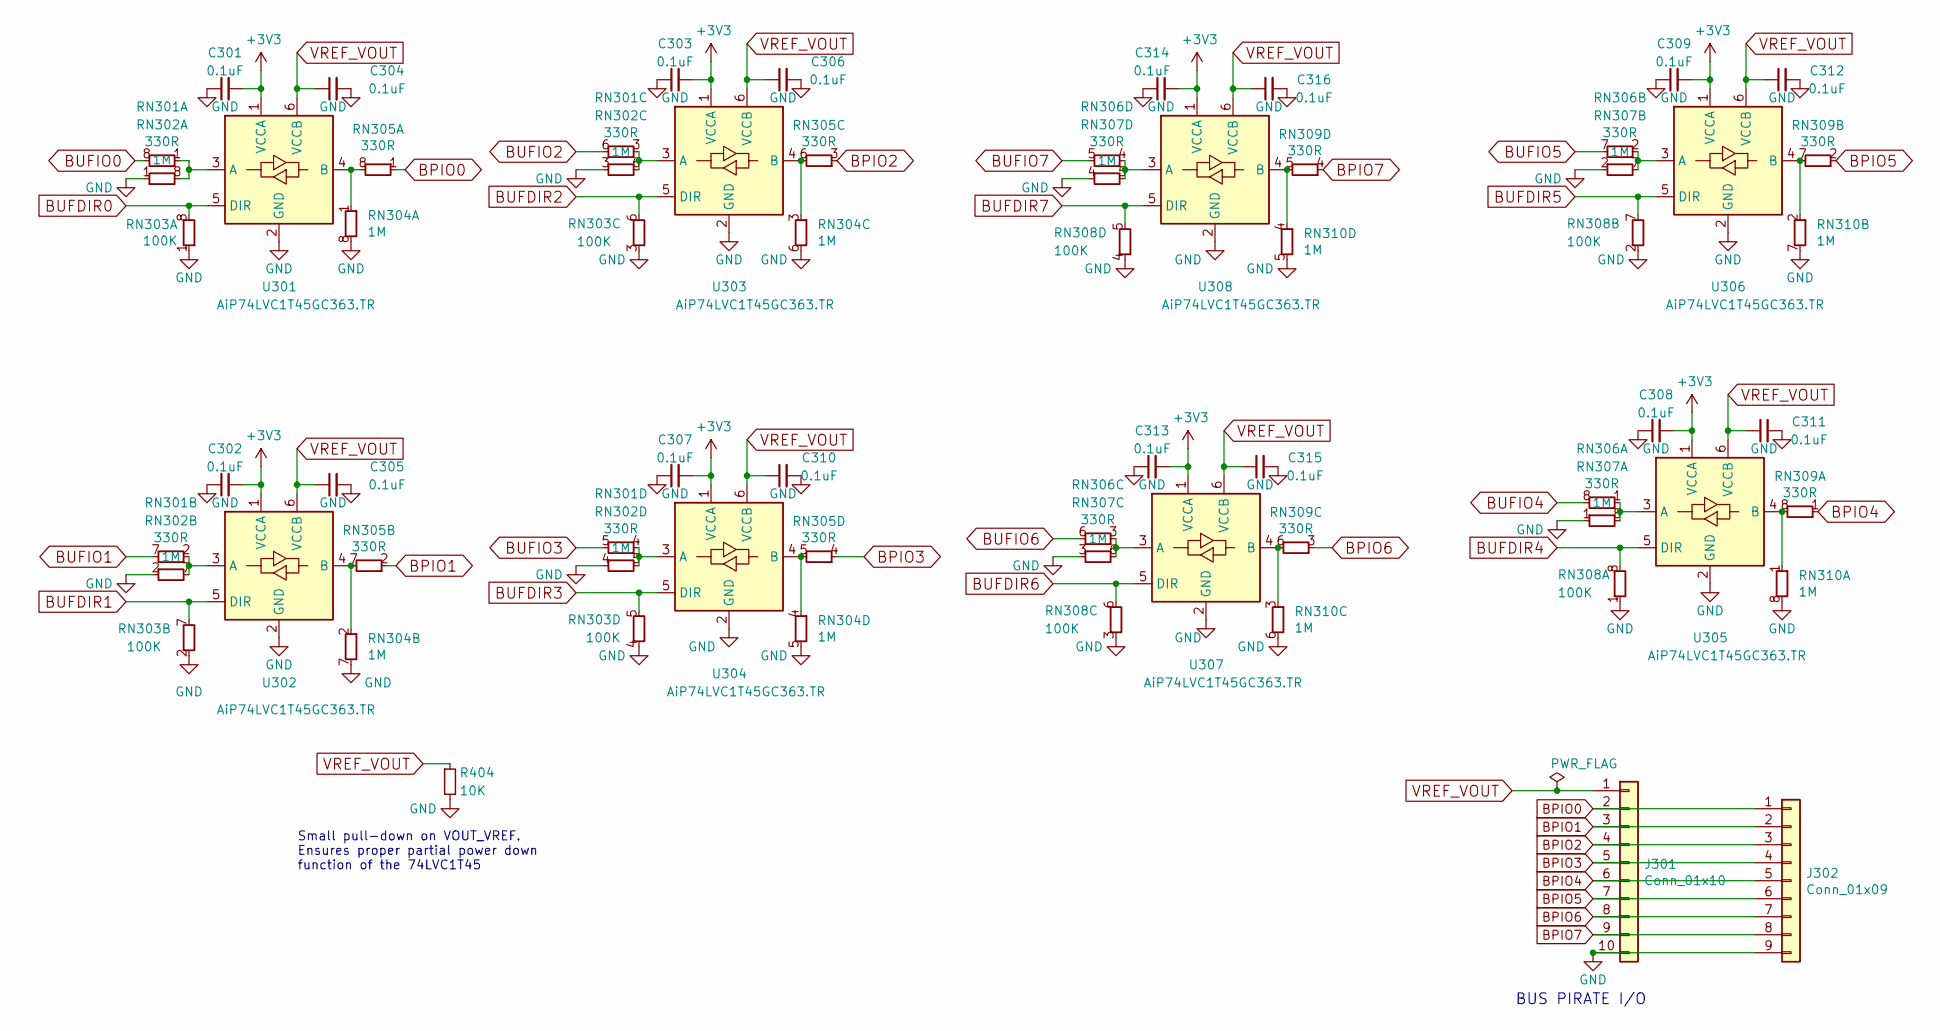
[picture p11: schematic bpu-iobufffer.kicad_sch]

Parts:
C301, C302, C303, C304, C305, C306, C307, C308, C309, C310, C311, C312, C313, C314, C315, C316: 0.1uF; C_0402_1005Metric
J301: Conn_01x10; PinHeader_1x10_P2.54mm_Vertical
J302: Conn_01x09; JST_SH_SM09B-SRSS-TB_1x09-1MP_P1.00mm_Horizontal
R404: 10K; R_0402_1005Metric
RN301, RN305, RN306, RN309: 330R; R_Array_Convex_4x0402
RN302, RN304, RN307, RN310: 1M; R_Array_Convex_4x0402
RN303, RN308: 100K; R_Array_Convex_4x0402
U301, U302, U303, U304, U305, U306, U307, U308: AiP74LVC1T45GC363.TR; SOT-363_SC-70-6

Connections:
BPIO0: J301.2, J302.1, RN305.1 (R1.1); also elsewhere on the board
BPIO1: J301.3, J302.2, RN305.2 (R1.1); also elsewhere on the board
BPIO2: J301.4, J302.3, RN305.3 (R1.1); also elsewhere on the board
BPIO3: J301.5, J302.4, RN305.4 (R1.1); also elsewhere on the board
BPIO4: J301.6, J302.5, RN309.1 (R1.1); also elsewhere on the board
BPIO5: J301.7, J302.6, RN309.2 (R1.1); also elsewhere on the board
BPIO6: J301.8, J302.7, RN309.3 (R1.1); also elsewhere on the board
BPIO7: J301.9, J302.8, RN309.4 (R1.1); also elsewhere on the board
BUFDIR0: RN303.8 (R1.8), U301.5 (DIR); also elsewhere on the board
BUFDIR1: RN303.7 (R1.8), U302.5 (DIR); also elsewhere on the board
BUFDIR2: RN303.6 (R1.8), U303.5 (DIR); also elsewhere on the board
BUFDIR3: RN303.5 (R1.8), U304.5 (DIR); also elsewhere on the board
BUFDIR4: RN308.8 (R1.8), U305.5 (DIR); also elsewhere on the board
BUFDIR5: RN308.7 (R1.8), U306.5 (DIR); also elsewhere on the board
BUFDIR6: RN308.6 (R1.8), U307.5 (DIR); also elsewhere on the board
BUFDIR7: RN308.5 (R1.8), U308.5 (DIR); also elsewhere on the board
BUFIO0: RN301.8 (R1.8); also elsewhere on the board
BUFIO1: RN301.7 (R1.8); also elsewhere on the board
BUFIO2: RN301.6 (R1.8); also elsewhere on the board
BUFIO3: RN301.5 (R1.8); also elsewhere on the board
BUFIO4: RN306.8 (R1.8); also elsewhere on the board
BUFIO5: RN306.7 (R1.8); also elsewhere on the board
BUFIO6: RN306.6 (R1.8); also elsewhere on the board
BUFIO7: RN306.5 (R1.8); also elsewhere on the board
unnamed: RN301.1 (R1.1), RN302.8 (R1.8), U301.3 (A)
unnamed: RN301.2 (R1.1), RN302.7 (R1.8), U302.3 (A)
unnamed: RN301.3 (R1.1), RN302.6 (R1.8), U303.3 (A)
unnamed: RN301.4 (R1.1), RN302.5 (R1.8), U304.3 (A)
unnamed: RN304.1 (R1.1), RN305.8 (R1.8), U301.4 (B)
unnamed: RN304.2 (R1.1), RN305.7 (R1.8), U302.4 (B)
unnamed: RN304.3 (R1.1), RN305.6 (R1.8), U303.4 (B)
unnamed: RN304.4 (R1.1), RN305.5 (R1.8), U304.4 (B)
unnamed: RN306.1 (R1.1), RN307.8 (R1.8), U305.3 (A)
unnamed: RN306.2 (R1.1), RN307.7 (R1.8), U306.3 (A)
unnamed: RN306.3 (R1.1), RN307.6 (R1.8), U307.3 (A)
unnamed: RN306.4 (R1.1), RN307.5 (R1.8), U308.3 (A)
unnamed: RN309.8 (R1.8), RN310.1 (R1.1), U305.4 (B)
unnamed: RN309.7 (R1.8), RN310.2 (R1.1), U306.4 (B)
unnamed: RN309.6 (R1.8), RN310.3 (R1.1), U307.4 (B)
unnamed: RN309.5 (R1.8), RN310.4 (R1.1), U308.4 (B)

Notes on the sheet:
Small pull-down on VOUT_VREF. Ensures proper partial power down function of the 74LVC1T45
BUS PIRATE I/O

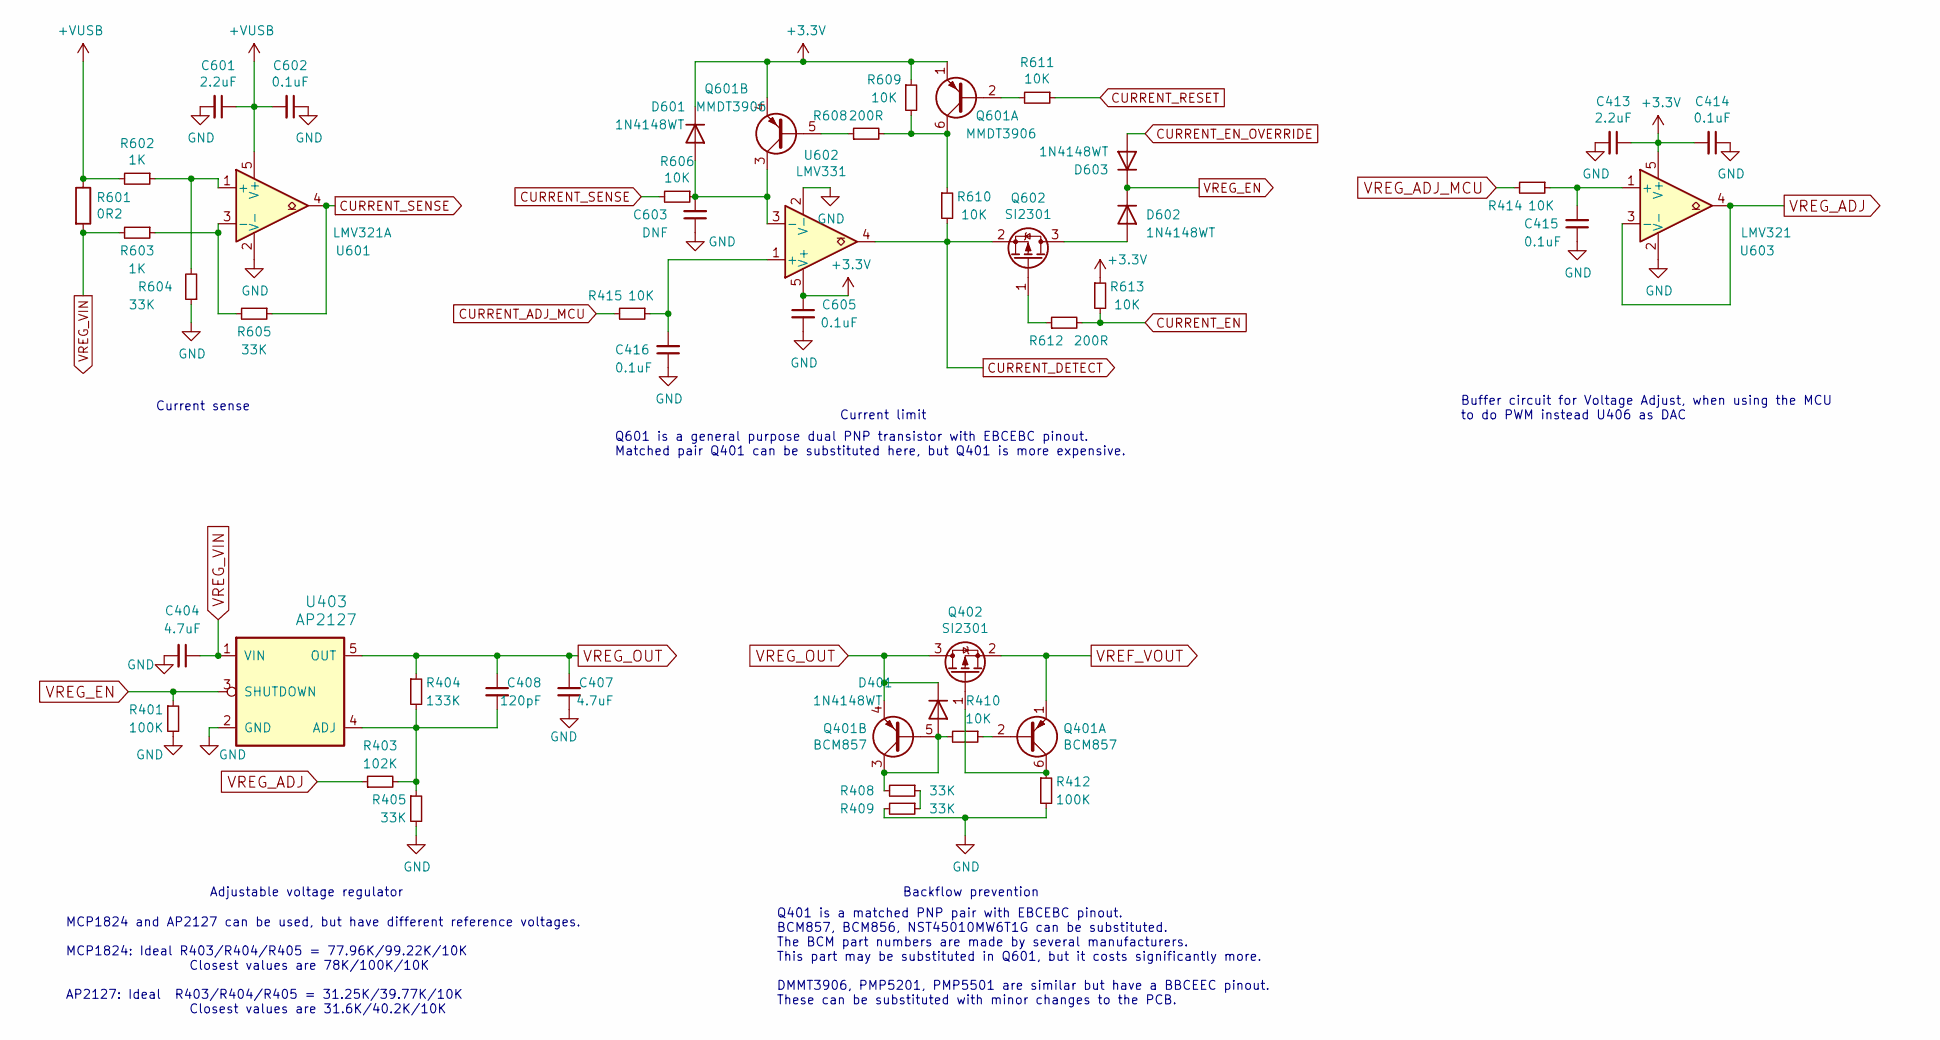
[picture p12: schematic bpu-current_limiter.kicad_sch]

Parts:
C404, C407: 4.7uF; C_0402_1005Metric
C408: 120pF; C_0402_1005Metric
C413, C601: 2.2uF; C_0402_1005Metric
C414, C415, C416, C602, C605: 0.1uF; C_0402_1005Metric
C603: DNF; C_0402_1005Metric
D401, D601, D602, D603: 1N4148WT; D_SOD-523
Q401: BCM857; SOT-363_SC-70-6
Q402, Q602: SI2301; SOT-523
Q601: MMDT3906; SOT-363_SC-70-6
R401, R412: 100K; R_0402_1005Metric
R403: 102K; R_0402_1005Metric
R404: 133K; R_0402_1005Metric
R405, R408, R409, R604, R605: 33K; R_0402_1005Metric
R410, R414, R415, R606, R609, R610, R611, R613: 10K; R_0402_1005Metric
R601: 0R2; R_2512_6332Metric_Pad1.40x3.35mm_HandSolder
R602, R603: 1K; R_0402_1005Metric
R608, R612: 200R; R_0402_1005Metric
U403: AP2127; SOT-23-5
U601: LMV321A; SOT-23-5
U602: LMV331; SOT-23-5
U603: LMV321; SOT-23-5

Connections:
+VUSB: C601.1, C602.2, R601.1, R602.2, U601.5 (V+); also elsewhere on the board
CURRENT_ADJ_MCU: R415.2; also elsewhere on the board
CURRENT_DETECT: Q602.2 (S), R610.2, U602.4; also elsewhere on the board
CURRENT_EN: R612.2, R613.2; also elsewhere on the board
CURRENT_EN_OVERRIDE: D603.2 (A); also elsewhere on the board
CURRENT_RESET: R611.1; also elsewhere on the board
CURRENT_SENSE: R605.1, R606.2, U601.4; also elsewhere on the board
unnamed: D401.2 (A), Q401.3 (C2), Q401.5 (B2), R408.2, R410.2
unnamed: C603.2, D601.2 (A), Q601.3 (C2), R606.1, U602.3 (-)
unnamed: D602.2 (A), Q602.3 (D)
unnamed: Q401.2 (B1), R410.1
unnamed: Q401.6 (C1), Q402.1 (G), R412.1
unnamed: Q601.2 (B1), R611.2
unnamed: Q601.6 (C1), R608.2, R609.2, R610.1
unnamed: Q601.5 (B2), R608.1
unnamed: Q602.1 (G), R612.1
unnamed: R408.1, R409.1
unnamed: R602.1, R604.2, U601.1 (+)
unnamed: R603.1, R605.2, U601.3 (-)
unnamed: C416.2, R415.1, U602.1 (+)
unnamed: C415.2, R414.1, U603.1 (+)
VREG_ADJ: R403.1, U603.3 (-), U603.4
VREG_ADJ_MCU: R414.2; also elsewhere on the board
VREG_EN: D602.1 (K), D603.1 (K), R401.1, U403.3 (SHUTDOWN)
VREG_VIN: C404.1, R601.2, R603.2, U403.1 (VIN)

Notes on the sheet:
Adjustable voltage regulator
Buffer circuit for Voltage Adjust, when using the MCU to do PWM instead U406 as DAC
Current sense
Backflow prevention
MCP1824 and AP2127 can be used, but have different reference voltages. MCP1824: Ideal R403/R404/R405 = 77.96K/99.22K/10K Closest values are 78K/100K/10K AP2127: Ideal R403/R404/R405 = 31.25K/39.77K/10K Closest values are 31.6K/40.2K/10K
Current limit
Q401 is a matched PNP pair with EBCEBC pinout. BCM857, BCM856, NST45010MW6T1G can be substituted. The BCM part numbers are made by several manufacturers. This part may be substituted in Q601, but it costs significantly more. DMMT3906, PMP5201, PMP5501 are similar but have a BBCEEC pinout. These can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
Q601 is a general purpose dual PNP transistor with EBCEBC pinout. Matched pair Q401 can be substituted here, but Q401 is more expensive.

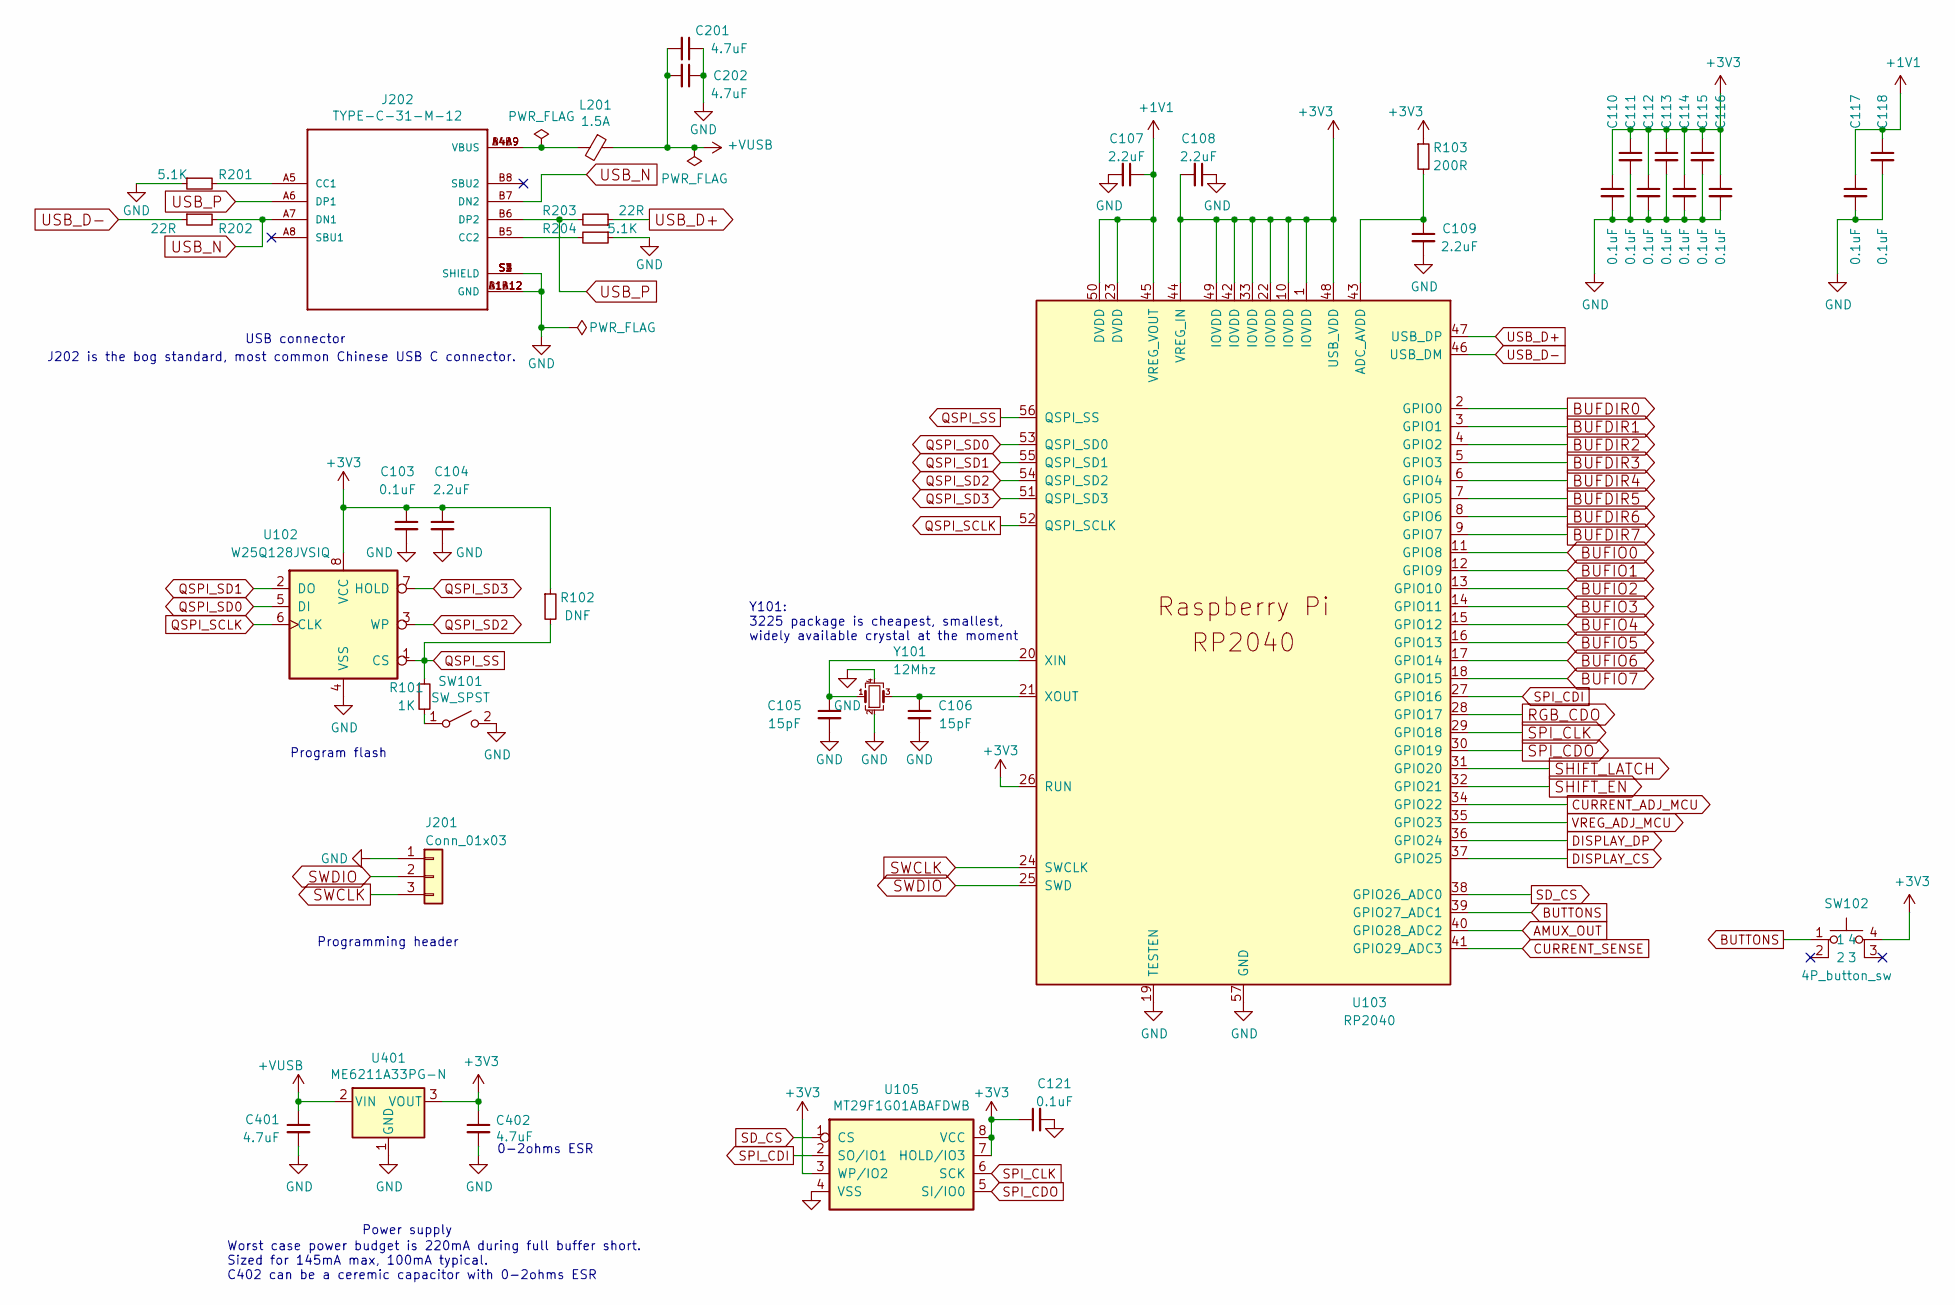
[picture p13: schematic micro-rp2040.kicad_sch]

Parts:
C103, C110, C111, C112, C113, C114, C115, C116, C117, C118, C121: 0.1uF; C_0402_1005Metric
C104, C107, C108, C109: 2.2uF; C_0402_1005Metric
C105, C106: 15pF; C_0402_1005Metric
C201, C202, C401, C402: 4.7uF; C_0402_1005Metric
J201: Conn_01x03; PinSocket_1x03_P2.54mm_Vertical
J202: TYPE-C-31-M-12; HRO_TYPE-C-31-M-12
L201: 1.5A; L_0805_2012Metric
R101: 1K; R_0402_1005Metric
R102: DNF; R_0402_1005Metric
R103: 200R; R_0402_1005Metric
R201, R204: 5.1K; R_0402_1005Metric
R202, R203: 22R; R_0402_1005Metric
SW101: SW_SPST; SW_SPST_PTS810
SW102: 4P_button_sw; GT-TC026X-HXXX-LX
U102: W25Q128JVSIQ; SOP-8_5.28x5.23mm_P1.27mm
U103: RP2040; RP2040-QFN-56
U105: MT29F1G01ABAFDWB; U-PDFN-8
U401: ME6211A33PG-N; SOT-89-3
Y101: 12Mhz; Crystal_SMD_3225-4Pin_3.2x2.5mm

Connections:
+1V1: C107.1, C117.1, C118.1, U103.23 (DVDD), U103.45 (VREG_VOUT), U103.50 (DVDD)
+VUSB: C201.2, C202.2, C401.1, L201.1, U401.2 (VIN); also elsewhere on the board
AMUX_OUT: U103.40 (GPIO28_ADC2); also elsewhere on the board
BUFDIR0: U103.2 (GPIO0); also elsewhere on the board
BUFDIR1: U103.3 (GPIO1); also elsewhere on the board
BUFDIR2: U103.4 (GPIO2); also elsewhere on the board
BUFDIR3: U103.5 (GPIO3); also elsewhere on the board
BUFDIR4: U103.6 (GPIO4); also elsewhere on the board
BUFDIR5: U103.7 (GPIO5); also elsewhere on the board
BUFDIR6: U103.8 (GPIO6); also elsewhere on the board
BUFDIR7: U103.9 (GPIO7); also elsewhere on the board
BUFIO0: U103.11 (GPIO8); also elsewhere on the board
BUFIO1: U103.12 (GPIO9); also elsewhere on the board
BUFIO2: U103.13 (GPIO10); also elsewhere on the board
BUFIO3: U103.14 (GPIO11); also elsewhere on the board
BUFIO4: U103.15 (GPIO12); also elsewhere on the board
BUFIO5: U103.16 (GPIO13); also elsewhere on the board
BUFIO6: U103.17 (GPIO14); also elsewhere on the board
BUFIO7: U103.18 (GPIO15); also elsewhere on the board
BUTTONS: SW102.1, U103.39 (GPIO27_ADC1)
CURRENT_ADJ_MCU: U103.34 (GPIO22); also elsewhere on the board
CURRENT_SENSE: U103.41 (GPIO29_ADC3); also elsewhere on the board
DISPLAY_CS: U103.37 (GPIO25); also elsewhere on the board
DISPLAY_DP: U103.36 (GPIO24); also elsewhere on the board
unnamed: J202.A5 (CC1), R201.2
unnamed: J202.B5 (CC2), R204.2
unnamed: J202.A4B9 (VBUS), J202.B4A9 (VBUS), L201.2
unnamed: R101.2, SW101.1 (A)
unnamed: C109.1, R103.2, U103.43 (ADC_AVDD)
unnamed: C105.1, U103.20 (XIN), Y101.1
unnamed: C106.1, U103.21 (XOUT), Y101.3
QSPI_SCLK: U102.6 (CLK), U103.52 (QSPI_SCLK)
QSPI_SD0: U102.5 (DI), U103.53 (QSPI_SD0)
QSPI_SD1: U102.2 (DO), U103.55 (QSPI_SD1)
QSPI_SD2: U102.3 (WP), U103.54 (QSPI_SD2)
QSPI_SD3: U102.7 (HOLD), U103.51 (QSPI_SD3)
QSPI_SS: R101.1, R102.2, U102.1 (CS), U103.56 (QSPI_SS)
RGB_CDO: U103.28 (GPIO17); also elsewhere on the board
SD_CS: U103.38 (GPIO26_ADC0), U105.1 (CS)
SHIFT_EN: U103.32 (GPIO21); also elsewhere on the board
SHIFT_LATCH: U103.31 (GPIO20); also elsewhere on the board
SPI_CDI: U103.27 (GPIO16), U105.2 (SO/IO1)
SPI_CDO: U103.30 (GPIO19), U105.5 (SI/IO0); also elsewhere on the board
SPI_CLK: U103.29 (GPIO18), U105.6 (SCK); also elsewhere on the board
SWCLK: J201.3, U103.24 (SWCLK)
SWDIO: J201.2, U103.25 (SWD)
USB_D+: R203.1, U103.47 (USB_DP)
USB_D-: R202.1, U103.46 (USB_DM)
USB_N: J202.A7 (DN1), J202.B7 (DN2), R202.2
USB_P: J202.A6 (DP1), J202.B6 (DP2), R203.2
VREG_ADJ_MCU: U103.35 (GPIO23); also elsewhere on the board

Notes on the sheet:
USB connector
Y101: 3225 package is cheapest, smallest, widely available crystal at the moment
Power supply
J202 is the bog standard, most common Chinese USB C connector.
Program flash
Worst case power budget is 220mA during full buffer short. Sized for 145mA max, 100mA typical. C402 can be a ceremic capacitor with 0-2ohms ESR
Programming header
0-2ohms ESR

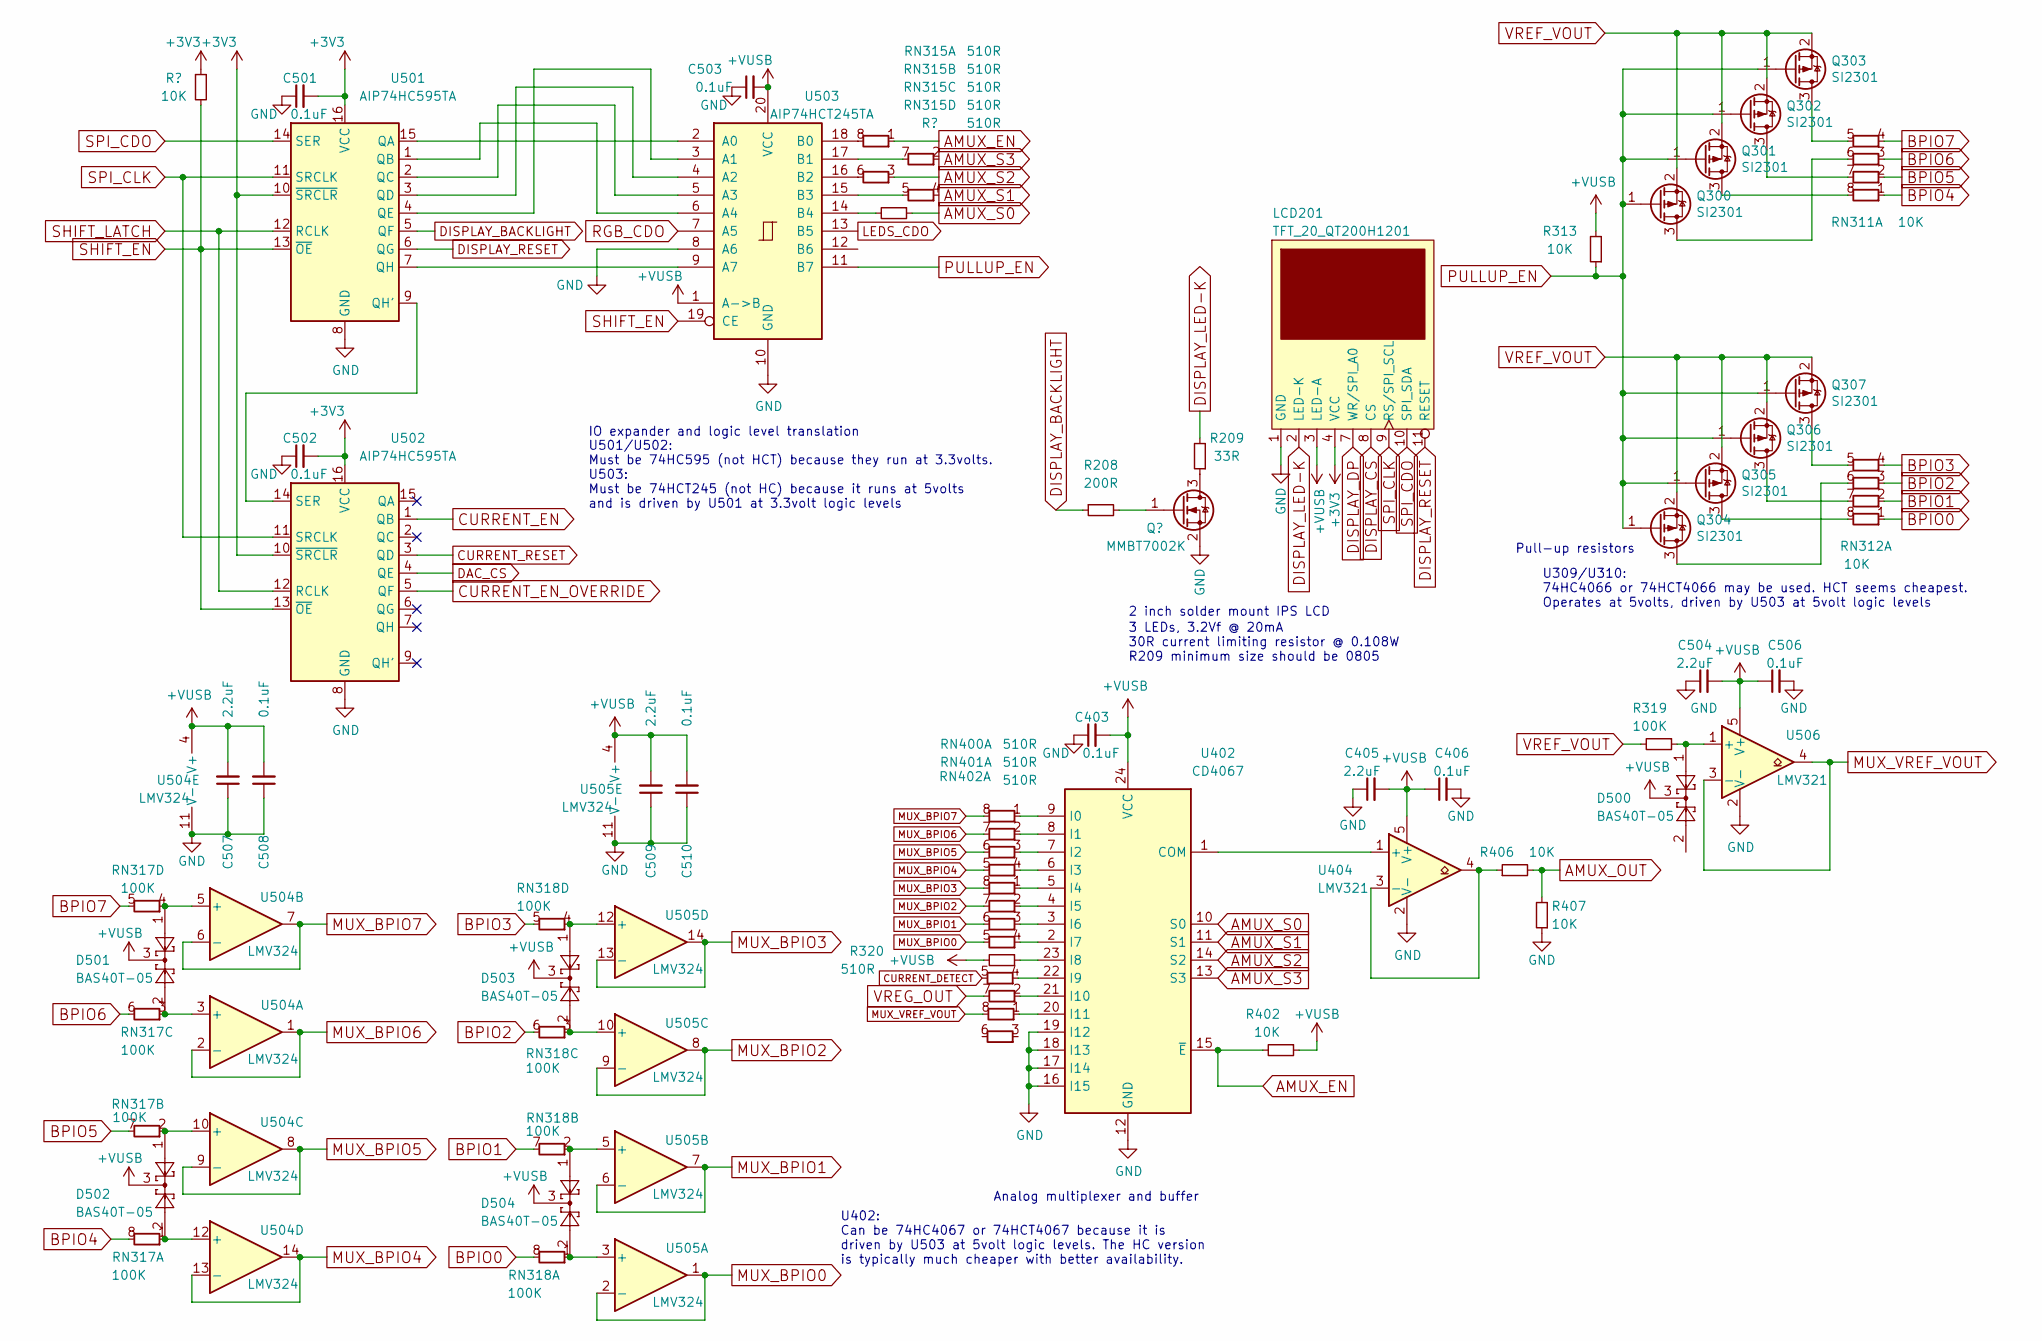
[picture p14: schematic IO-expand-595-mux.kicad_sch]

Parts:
C403, C406, C501, C502, C503, C506, C508, C510: 0.1uF; C_0402_1005Metric
C405, C504, C507, C509: 2.2uF; C_0402_1005Metric
D500, D501, D502, D503, D504: BAS40T-05; SOT-523
LCD201: TFT_20_QT200H1201
Q202: MMBT7002K; SOT-23
Q300, Q301, Q302, Q303, Q304, Q305, Q306, Q307: SI2301; SOT-523
R208: 200R; R_0402_1005Metric
R209: 33R; R_0805_2012Metric
R313, R402, R406, R407, R501: 10K; R_0402_1005Metric
R316, R320: 510R; R_0402_1005Metric
R319: 100K; R_0402_1005Metric
RN311, RN312: 10K; R_Array_Convex_4x0402
RN315, RN400, RN401, RN402: 510R; R_Array_Convex_4x0402
RN317, RN318: 100K; R_Array_Convex_4x0402
U402: CD4067; TSSOP-24_4.4x7.8mm_P0.65mm
U404, U506: LMV321; SOT-23-5
U501, U502: AIP74HC595TA; TSSOP-16_4.4x5mm_P0.65mm
U503: AIP74HCT245TA; TSSOP-20_4.4x6.5mm_P0.65mm
U504, U505: LMV324; TSSOP-14_4.4x5mm_P0.65mm

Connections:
+VUSB: C403.2, C405.2, C406.1, C503.2, C504.2, C506.1, C507.2, C508.2, C509.2, C510.2, D500.3, D501.3, D502.3, D503.3, D504.3, LCD201.3 (LED-A), R313.2, R320.2, R402.1, U402.24 (VCC), U404.5 (V+), U503.1 (A->B), U503.20 (VCC), U504.4 (V+), U505.4 (V+), U506.5 (V+); also elsewhere on the board
AMUX_EN: R402.2, RN315.1 (R1.1), U402.15 (~E)
AMUX_OUT: R406.2, R407.2; also elsewhere on the board
AMUX_S0: R316.1, U402.10 (S0)
AMUX_S1: RN315.4 (R1.1), U402.11 (S1)
AMUX_S2: RN315.3 (R1.1), U402.14 (S2)
AMUX_S3: RN315.2 (R1.1), U402.13 (S3)
BPIO0: RN312.1 (R1.1), RN318.8 (R1.8); also elsewhere on the board
BPIO1: RN312.2 (R1.1), RN318.7 (R1.8); also elsewhere on the board
BPIO2: RN312.3 (R1.1), RN318.6 (R1.8); also elsewhere on the board
BPIO3: RN312.4 (R1.1), RN318.5 (R1.8); also elsewhere on the board
BPIO4: RN311.1 (R1.1), RN317.8 (R1.8); also elsewhere on the board
BPIO5: RN311.2 (R1.1), RN317.7 (R1.8); also elsewhere on the board
BPIO6: RN311.3 (R1.1), RN317.6 (R1.8); also elsewhere on the board
BPIO7: RN311.4 (R1.1), RN317.5 (R1.8); also elsewhere on the board
CURRENT_DETECT: RN402.5 (R1.8); also elsewhere on the board
CURRENT_EN: U502.1 (QB); also elsewhere on the board
CURRENT_EN_OVERRIDE: U502.5 (QF); also elsewhere on the board
CURRENT_RESET: U502.3 (QD); also elsewhere on the board
DAC_CS: U502.4 (QE)
DISPLAY_BACKLIGHT: R208.1, U501.5 (QF)
DISPLAY_CS: LCD201.8 (CS); also elsewhere on the board
DISPLAY_DP: LCD201.7 (WR/SPI_A0); also elsewhere on the board
DISPLAY_LED-K: LCD201.2 (LED-K), R209.2
DISPLAY_RESET: LCD201.11 (RESET), U501.6 (QG)
LEDS_CDO: U503.13 (B5); also elsewhere on the board
MUX_BPIO0: RN401.5 (R1.8), U505.1, U505.2 (-)
MUX_BPIO1: RN401.6 (R1.8), U505.6 (-), U505.7
MUX_BPIO2: RN401.7 (R1.8), U505.8, U505.9 (-)
MUX_BPIO3: RN401.8 (R1.8), U505.13 (-), U505.14
MUX_BPIO4: RN400.5 (R1.8), U504.13 (-), U504.14
MUX_BPIO5: RN400.6 (R1.8), U504.8, U504.9 (-)
MUX_BPIO6: RN400.7 (R1.8), U504.1, U504.2 (-)
MUX_BPIO7: RN400.8 (R1.8), U504.6 (-), U504.7
MUX_VREF_VOUT: RN402.8 (R1.8), U506.3 (-), U506.4
unnamed: Q202.3 (D), R209.1
unnamed: Q202.1 (G), R208.2
unnamed: Q300.3 (D), RN311.6 (R1.8)
unnamed: Q301.3 (D), RN311.8 (R1.8)
unnamed: Q302.3 (D), RN311.7 (R1.8)
unnamed: Q303.3 (D), RN311.5 (R1.8)
unnamed: Q304.3 (D), RN312.6 (R1.8)
unnamed: Q305.3 (D), RN312.8 (R1.8)
unnamed: Q306.3 (D), RN312.7 (R1.8)
unnamed: Q307.3 (D), RN312.5 (R1.8)
unnamed: RN315.8 (R1.8), U503.18 (B0)
unnamed: RN315.7 (R1.8), U503.17 (B1)
unnamed: RN315.6 (R1.8), U503.16 (B2)
unnamed: RN315.5 (R1.8), U503.15 (B3)
unnamed: D502.2, RN317.1 (R1.1), U504.12 (+)
unnamed: D502.1, RN317.2 (R1.1), U504.10 (+)
unnamed: D501.2, RN317.3 (R1.1), U504.3 (+)
unnamed: D501.1, RN317.4 (R1.1), U504.5 (+)
unnamed: D504.2, RN318.1 (R1.1), U505.3 (+)
unnamed: D504.1, RN318.2 (R1.1), U505.5 (+)
unnamed: D503.2, RN318.3 (R1.1), U505.10 (+)
unnamed: D503.1, RN318.4 (R1.1), U505.12 (+)
unnamed: RN400.1 (R1.1), U402.9 (I0)
unnamed: RN400.2 (R1.1), U402.8 (I1)
unnamed: RN400.3 (R1.1), U402.7 (I2)
unnamed: RN400.4 (R1.1), U402.6 (I3)
unnamed: RN401.1 (R1.1), U402.5 (I4)
unnamed: RN401.2 (R1.1), U402.4 (I5)
unnamed: RN401.3 (R1.1), U402.3 (I6)
unnamed: RN401.4 (R1.1), U402.2 (I7)
unnamed: RN402.1 (R1.1), U402.20 (I11)
unnamed: RN402.2 (R1.1), U402.21 (I10)
unnamed: RN402.4 (R1.1), U402.22 (I9)
unnamed: U402.1 (COM), U404.1 (+)
unnamed: R320.1, U402.23 (I8)
unnamed: R406.1, U404.3 (-), U404.4
unnamed: U501.15 (QA), U503.2 (A0)
unnamed: U501.1 (QB), U503.6 (A4)
unnamed: U501.2 (QC), U503.5 (A3)
unnamed: U501.3 (QD), U503.4 (A2)
unnamed: U501.4 (QE), U503.3 (A1)
unnamed: U501.9 (QH'), U502.14 (SER)
unnamed: U501.7 (QH), U503.9 (A7)
unnamed: R316.2, U503.14 (B4)
unnamed: D500.1, R319.1, U506.1 (+)
PULLUP_EN: Q300.1 (G), Q301.1 (G), Q302.1 (G), Q303.1 (G), Q304.1 (G), Q305.1 (G), Q306.1 (G), Q307.1 (G), R313.1, U503.11 (B7)
RGB_CDO: U503.7 (A5); also elsewhere on the board
SHIFT_EN: R501.2, U501.13 (~OE), U502.13 (~OE), U503.19 (CE); also elsewhere on the board
SHIFT_LATCH: U501.12 (RCLK), U502.12 (RCLK); also elsewhere on the board
SPI_CDO: LCD201.10 (SPI_SDA), U501.14 (SER); also elsewhere on the board
SPI_CLK: LCD201.9 (RS/SPI_SCL), U501.11 (SRCLK), U502.11 (SRCLK); also elsewhere on the board

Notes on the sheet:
IO expander and logic level translation
Analog multiplexer and buffer
U402: Can be 74HC4067 or 74HCT4067 because it is driven by U503 at 5volt logic levels. The HC version is typically much cheaper with better availability.
3 LEDs, 3.2Vf @ 20mA 30R current limiting resistor @ 0.108W R209 minimum size should be 0805
2 inch solder mount IPS LCD
U501/U502: Must be 74HC595 (not HCT) because they run at 3.3volts. U503: Must be 74HCT245 (not HC) because it runs at 5volts and is driven by U501 at 3.3volt logic levels
U309/U310: 74HC4066 or 74HCT4066 may be used. HCT seems cheapest. Operates at 5volts, driven by U503 at 5volt logic levels
Pull-up resistors

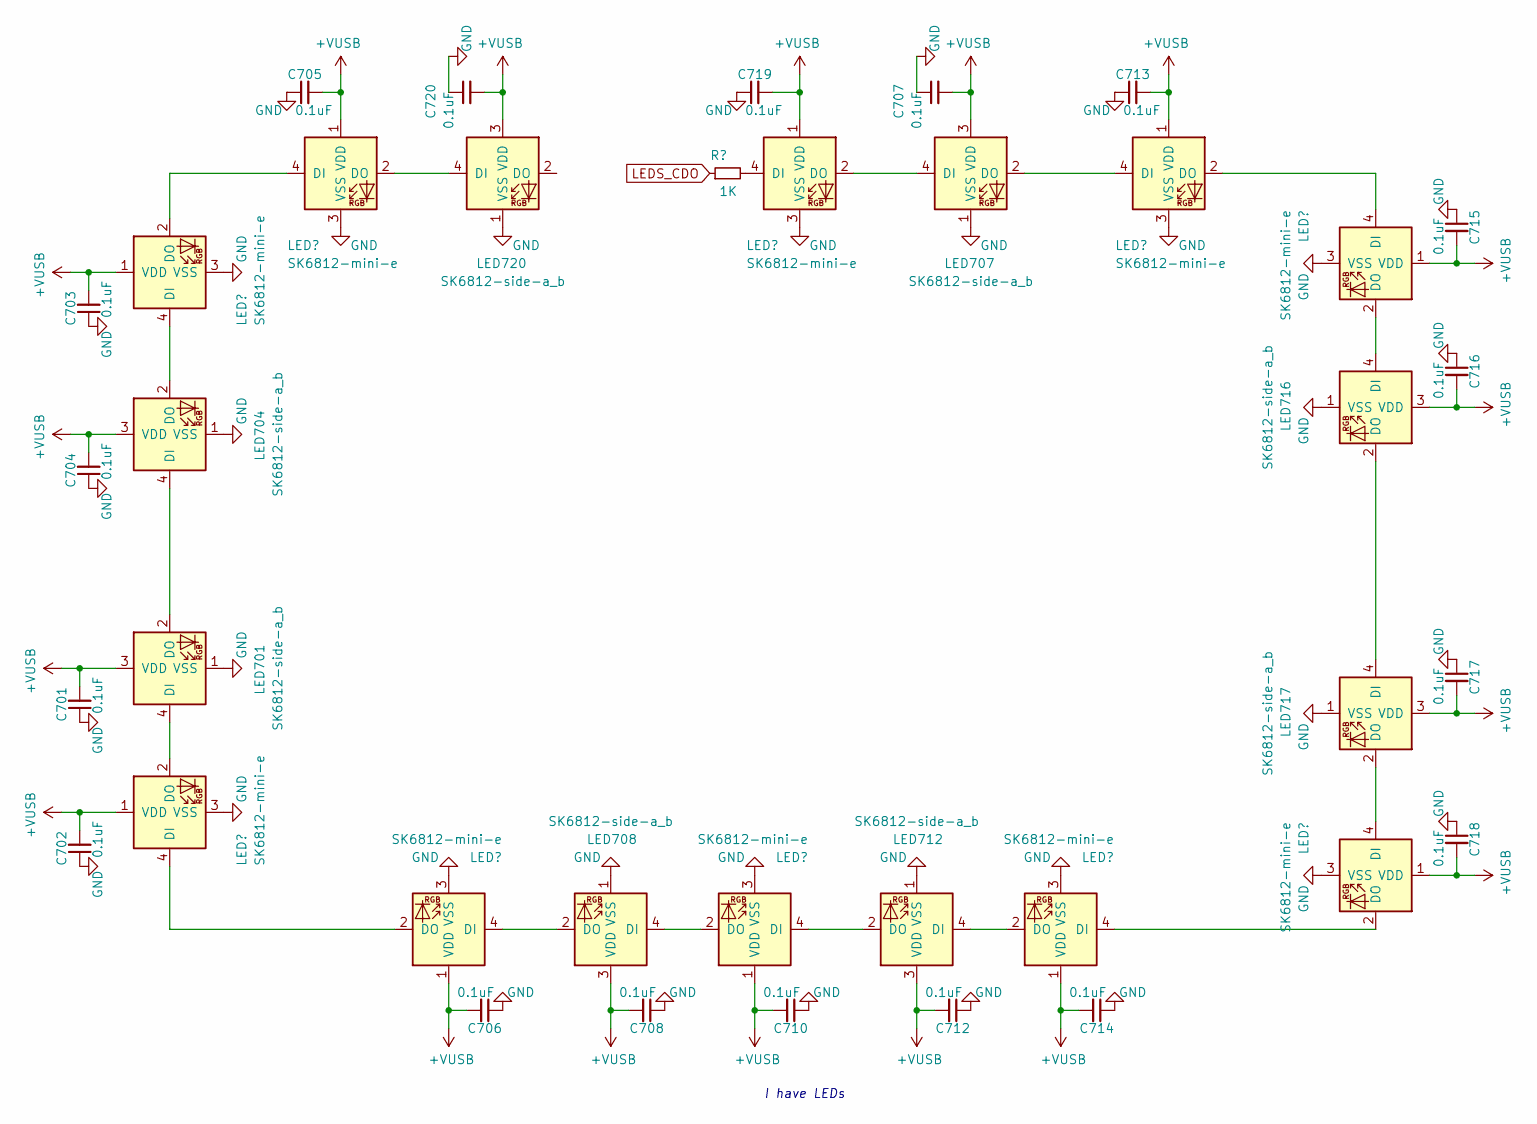
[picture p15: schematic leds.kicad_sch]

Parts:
C701, C702, C703, C704, C705, C706, C707, C708, C710, C712, C713, C714, C715, C716, C717, C718, C719, C720: 0.1uF; C_0402_1005Metric
LED701, LED704, LED707, LED708, LED712, LED716, LED717, LED720: SK6812-side-a_b
LED702, LED703, LED705, LED706, LED710, LED713, LED714, LED715, LED718, LED719: SK6812-mini-e
R502: 1K; R_0402_1005Metric

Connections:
+VUSB: C701.2, C702.2, C703.2, C704.2, C705.2, C706.2, C707.2, C708.2, C710.2, C712.2, C713.2, C714.2, C715.2, C716.2, C717.2, C718.2, C719.2, C720.2, LED701.3 (VDD), LED702.1 (VDD), LED703.1 (VDD), LED704.3 (VDD), LED705.1 (VDD), LED706.1 (VDD), LED707.3 (VDD), LED708.3 (VDD), LED710.1 (VDD), LED712.3 (VDD), LED713.1 (VDD), LED714.1 (VDD), LED715.1 (VDD), LED716.3 (VDD), LED717.3 (VDD), LED718.1 (VDD), LED719.1 (VDD), LED720.3 (VDD); also elsewhere on the board
LEDS_CDO: R502.1; also elsewhere on the board
unnamed: LED701.4 (DI), LED702.2 (DO)
unnamed: LED701.2 (DO), LED704.4 (DI)
unnamed: LED702.4 (DI), LED706.2 (DO)
unnamed: LED703.4 (DI), LED704.2 (DO)
unnamed: LED703.2 (DO), LED705.4 (DI)
unnamed: LED705.2 (DO), LED720.4 (DI)
unnamed: LED706.4 (DI), LED708.2 (DO)
unnamed: LED707.4 (DI), LED719.2 (DO)
unnamed: LED707.2 (DO), LED713.4 (DI)
unnamed: LED708.4 (DI), LED710.2 (DO)
unnamed: LED710.4 (DI), LED712.2 (DO)
unnamed: LED712.4 (DI), LED714.2 (DO)
unnamed: LED713.2 (DO), LED715.4 (DI)
unnamed: LED714.4 (DI), LED718.2 (DO)
unnamed: LED715.2 (DO), LED716.4 (DI)
unnamed: LED716.2 (DO), LED717.4 (DI)
unnamed: LED717.2 (DO), LED718.4 (DI)
unnamed: LED719.4 (DI), R502.2

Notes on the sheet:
I have LEDs

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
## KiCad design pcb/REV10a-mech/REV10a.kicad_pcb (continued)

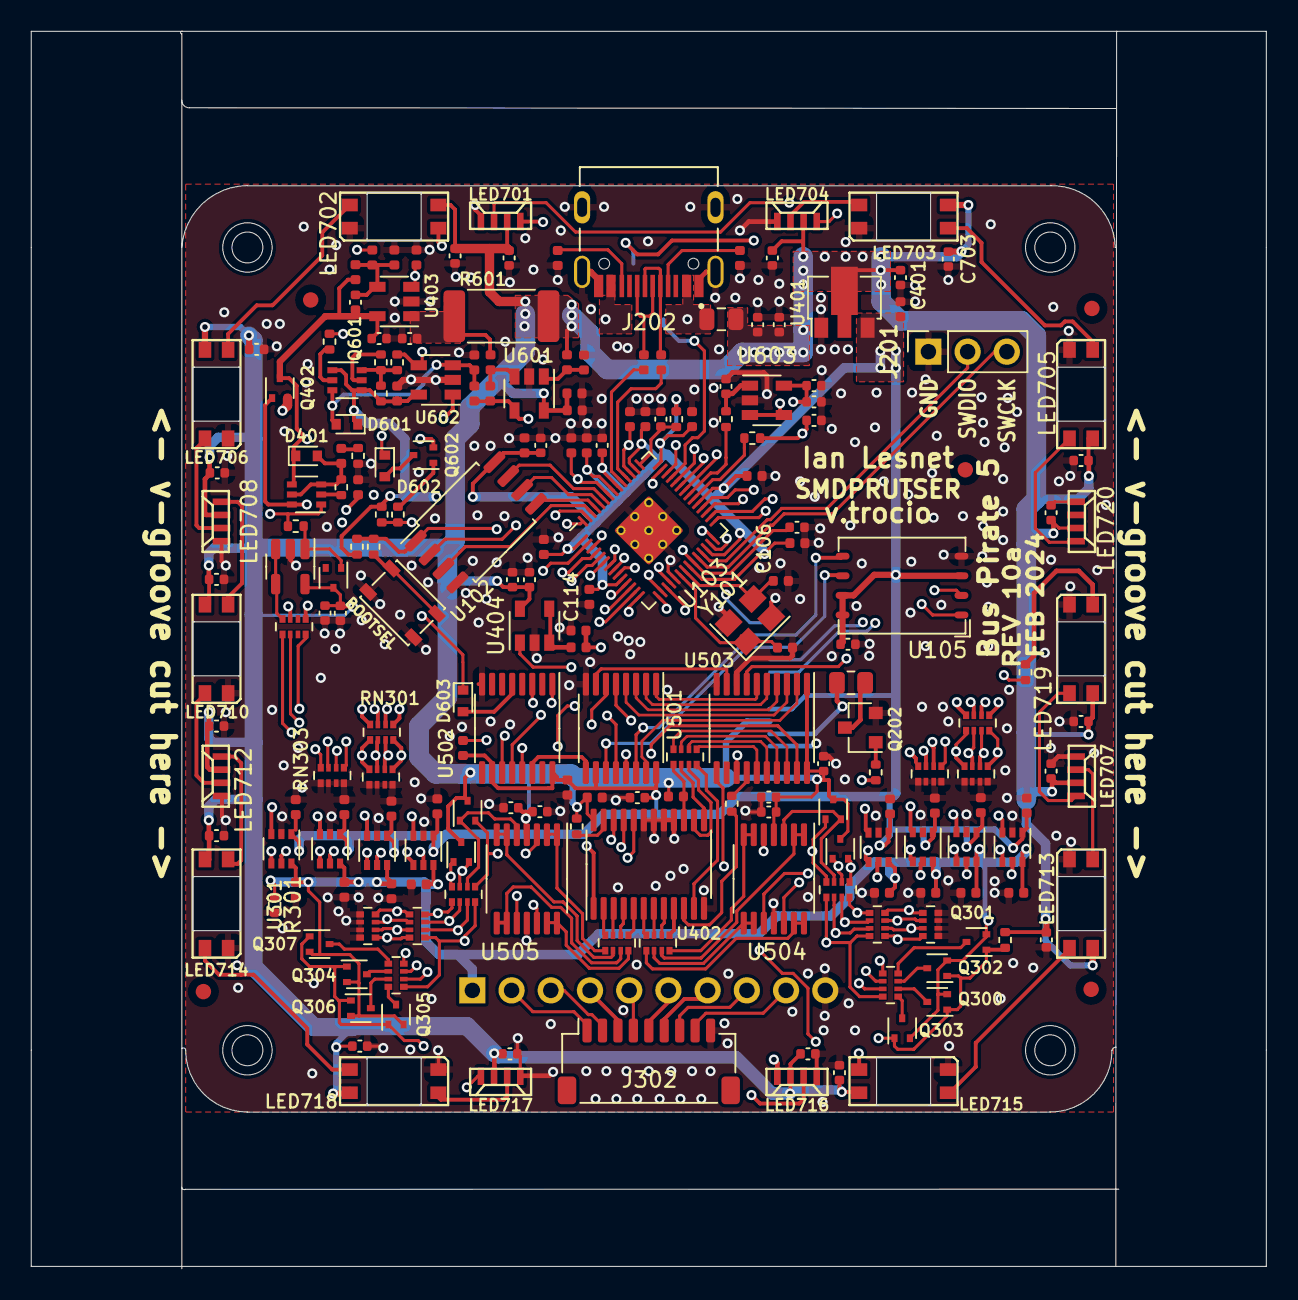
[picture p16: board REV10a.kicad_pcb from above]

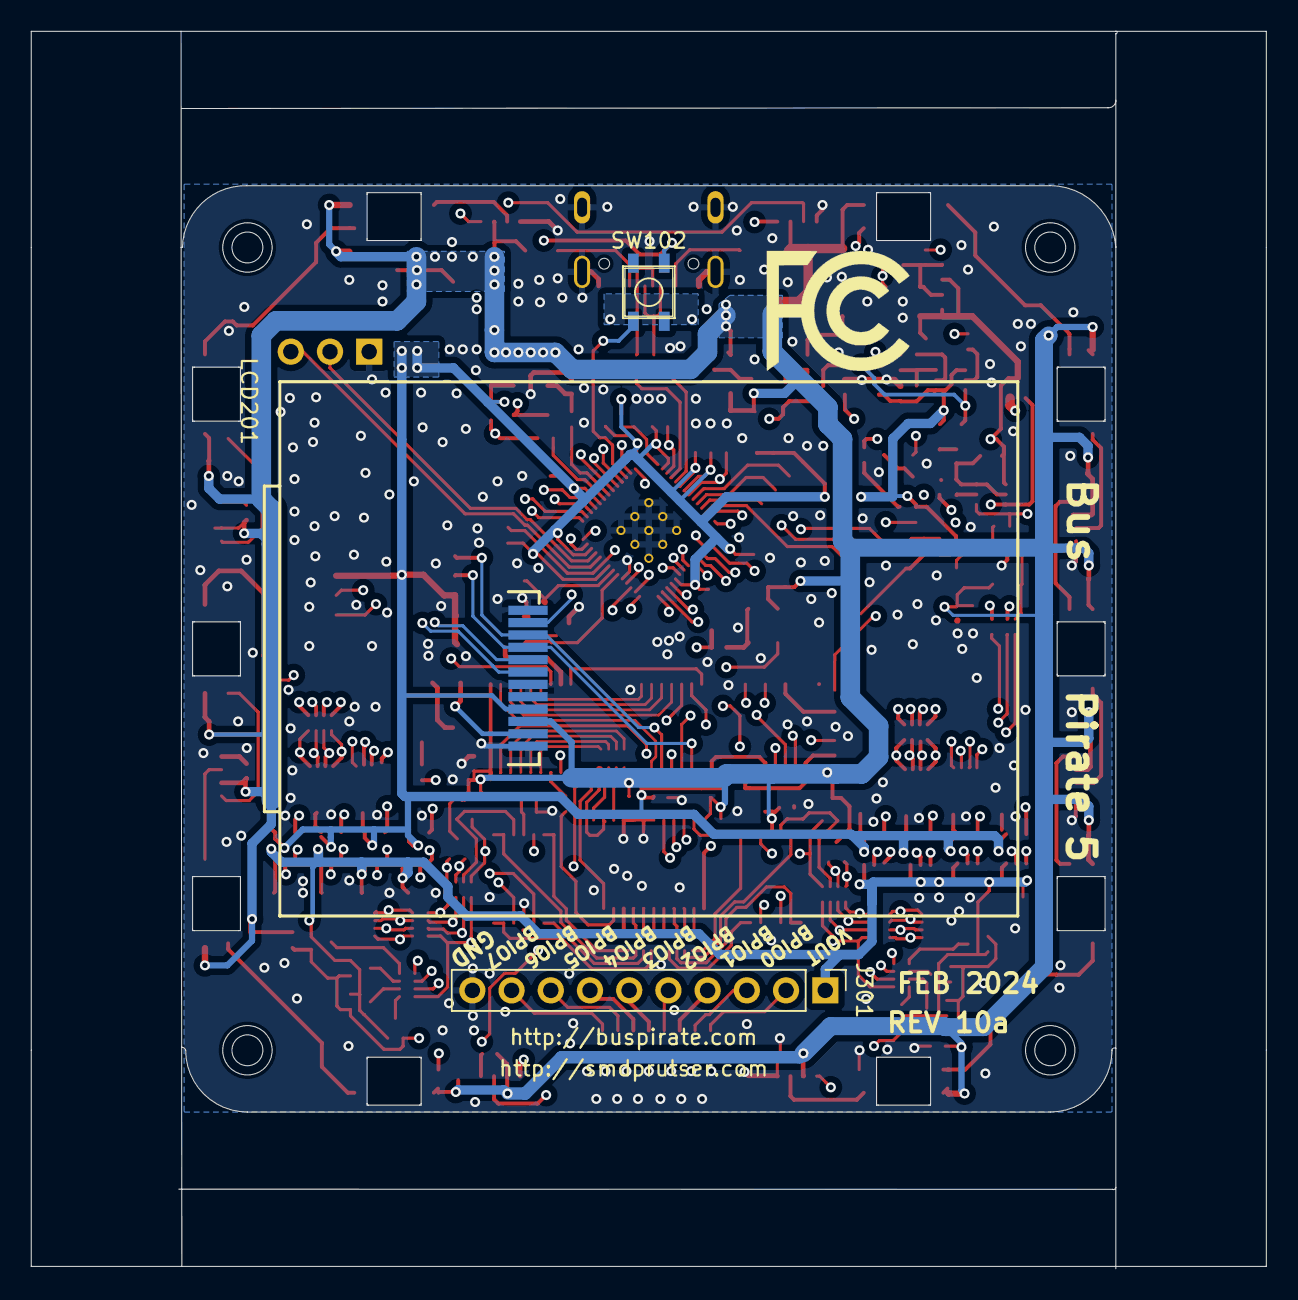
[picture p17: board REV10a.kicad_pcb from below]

Board: 4 copper layers, 80.0 x 80.0 mm, 220 parts (4 on the bottom side), 183 nets.

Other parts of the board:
R301: 10K; R_0402_1005Metric

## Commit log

2024-10-19 making chris branch
    [BusPirate-5-rev10.kicad_pcb, BusPirate-5-rev10.kicad_sch, IO-expand-595-mux.kicad_sch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]
2024-10-22 almost wrapped up
    [BusPirate-5-rev10.kicad_pcb, mech.kicad_pcb, mech.kicad_sch]
2024-10-25 clean up directory names
    [BusPirate-5-rev10.kicad_pcb, BusPirate-5-rev10.kicad_sch, IO-expand-595-mux.kicad_sch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]
2024-10-25 removed unrelated directories
    [bb-pin-v0.1.scad, bb-pin-v0.2.scad, bb-pin-v0.3.scad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]
2024-10-25 making readme comments
    [BusPirate5REV8-v10.scad, enc.scad, make2d.scad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]
2024-10-25 removed unnecessary PCB versions
    [5XL-REV0.kicad_pcb, 5XL-REV0.kicad_sch, 5XL-REV0.sch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]
